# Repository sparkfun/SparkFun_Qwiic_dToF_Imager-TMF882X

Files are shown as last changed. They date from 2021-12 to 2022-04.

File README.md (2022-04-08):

SparkFun Qwiic dTof Imager TMF882X
========================================

<table class="table table-hover table-striped table-bordered">
  <tr align="center">
   <td><a href="https://www.sparkfun.com/products/19036">Qwiic dToF Imager <br />TMF8820</a></td>
   <td><a href="https://www.sparkfun.com/products/19036">Qwiic Mini dToF Imager <br />TMF8820</a></td>
   <td><a href="https://www.sparkfun.com/products/19037">Qwiic dToF Imager <br />TMF8821</a></td>
   <td><a href="https://www.sparkfun.com/products/19037">Qwiic Mini dToF Imager <br />TMF8821</a></td>
  </tr>
  <tr align="center">
   <td><i>Qwiic dToF Imager TMF8820 <br />[ <a href="https://www.sparkfun.com/products/19036">SEN-19036</a> ]</i></td>
   <td><i>Qwiic Mini dToF Imager TMF8820 <br />[ <a href="https://www.sparkfun.com/products/19218">SEN-19218</a> ]</i></td>
   <td><i>Qwiic dToF Imager TMF8821 <br />[ <a href="https://www.sparkfun.com/products/19037">SEN-19037</a> ]</i></td>
   <td><i>Qwiic Mini dToF Imager TMF8821 <br />[ <a href="https://www.sparkfun.com/products/19451">SEN-19451</a> ]</i></td>
  </tr>
</table>

<Basic description of the part.>

Repository Contents
-------------------

* **/Documentation** - Data sheets, additional product information
* **/Hardware** - Eagle design files (.brd, .sch)
* **/Production** - Production panel files (.brd)

Documentation
--------------
  
* **[Installing an Arduino Library Guide](https://learn.sparkfun.com/tutorials/installing-an-arduino-library)** - Basic information on how to install an Arduino library.
* **[Library](https://github.com/sparkfun/SparkFun_TMF882X_dToF_Arduino_Library)** - Arduino library for the Qwiic dToF TMF8820 and TMF8821.
* **[Hookup Guide](https://learn.sparkfun.com/tutorials/2289)** - Basic hookup guide for the dToF TMF8820 and TMF8821 Sensors.

Product Versions
----------------
* [SEN-19036](https://www.sparkfun.com/products/19036) - Qwiic dToF Imager TMF8820
* [SEN-19218](https://www.sparkfun.com/products/19218) - Qwiic Mini dToF Imager TMF8820
* [SEN-19037](https://www.sparkfun.com/products/19037) - Qwiic dToF Imager TMF8821
* [SEN-19451](https://www.sparkfun.com/products/19451) - Qwiic Mini dToF Imager TMF8821

Version History
---------------
* v1.0 - Initial release

License Information
-------------------

This product is _**open source**_! 

Please review the LICENSE.md file for license information. 

If you have any questions or concerns on licensing, please contact technical support on our [SparkFun forums](https://forum.sparkfun.com/viewforum.php?f=152).

Distributed as-is; no warranty is given.

- Your friends at SparkFun.

_<COLLABORATION CREDIT>_

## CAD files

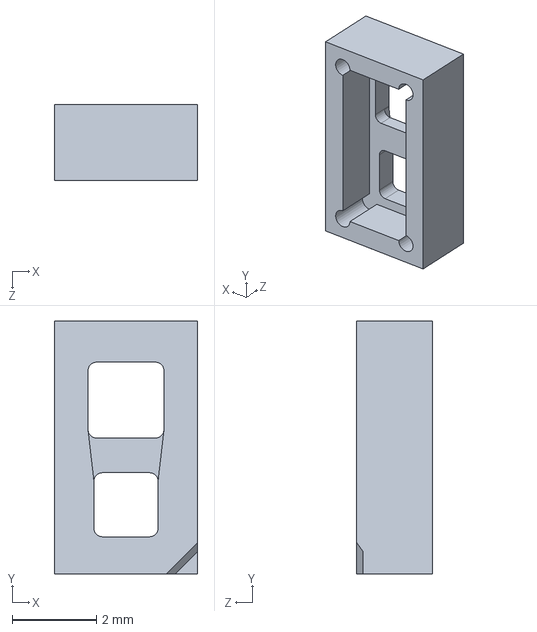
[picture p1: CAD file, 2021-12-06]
Documents/TMF882X_PD001043_1-00/RUBBERBOOT2.SLDPRT
3.40 x 6.00 x 1.80 mm

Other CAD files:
Documents/TMF882X_PD001043_1-00/RB_V2_06_02.STEP
Documents/TMF882X_PD001043_1-00/RUBBERBOOT2.SLDDRW

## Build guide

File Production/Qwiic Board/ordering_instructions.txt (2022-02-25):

panel size, 169x117mm
PCB thickness, 1.6mm
number of layers, 2
soldermask color, Red
silkscreen color, White
oz copper, 1oz
finish, HASL lead free
stencils, top
pcs per panel, 24
min trace width, 0.2032mm / 0.0080in
min drill size, 0.3048mm / 0.0120in

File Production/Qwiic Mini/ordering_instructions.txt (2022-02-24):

panel size, 169x133mm
PCB thickness, 1.6mm
number of layers, 2
soldermask color, Red
silkscreen color, White
oz copper, 1oz
finish, HASL lead free
stencils, top+bottom
pcs per panel, 54
min trace width, 0.2540mm / 0.0100in
min drill size, 0.3048mm / 0.0120in

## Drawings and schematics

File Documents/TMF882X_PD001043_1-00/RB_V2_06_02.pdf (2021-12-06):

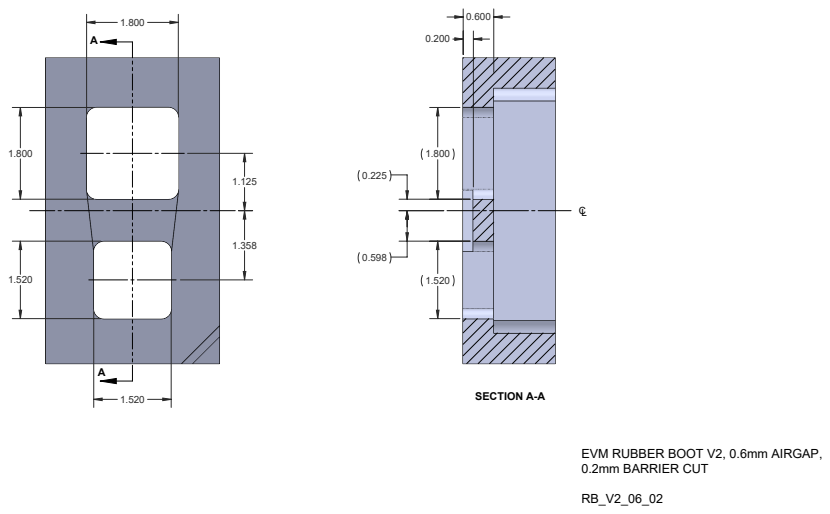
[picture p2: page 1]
SECTION A-A

EVM RUBBER BOOT V2, 0.6mm AIRGAP,
0.2mm BARRIER CUT

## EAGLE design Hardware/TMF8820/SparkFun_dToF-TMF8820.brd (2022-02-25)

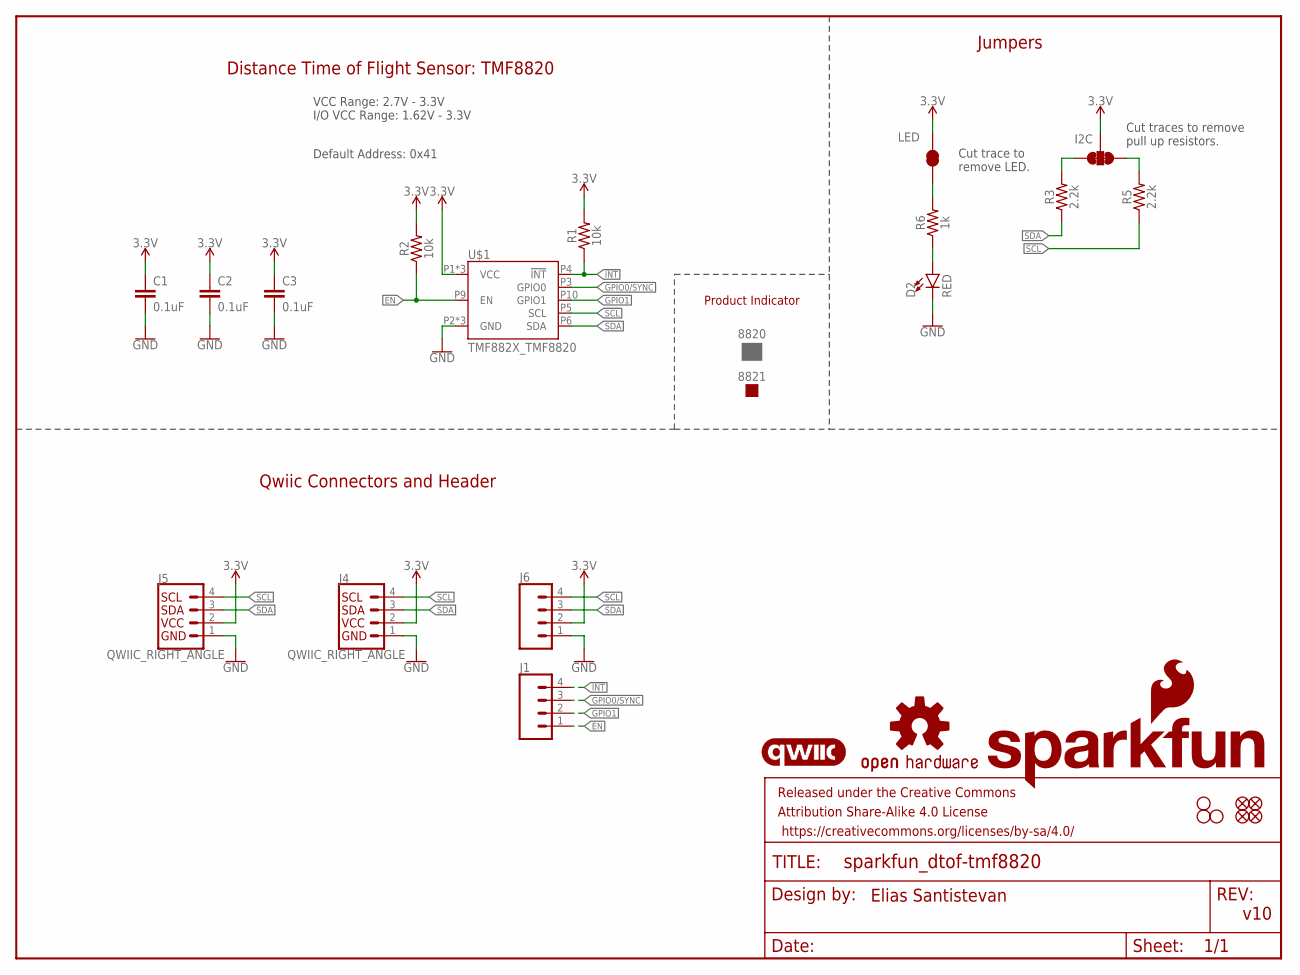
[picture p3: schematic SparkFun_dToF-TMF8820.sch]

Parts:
8820: PROD_ID_PASTE_SILK; PRODUCT_IDENT_PASTE_SILK
8821: PROD_ID_NO-PASTE_SILK; PRODUCT_IDENT_NO_SILK
C1, C2, C3: 0.1uF; 0402-TIGHT
D2: RED; LED-0603
FD5, FD6, FD7, FD8: FIDUCIALUFIDUCIAL; FIDUCIAL-MICRO
FRAME2: FRAME-LETTER; CREATIVE_COMMONS
H5, H6, H8: STAND-OFFTIGHT; STAND-OFF-TIGHT
I2C: I2C_PU; SMT-JUMPER_3_2-NC_TRACE_SILK
J1: CONN_041X04_NO_SILK_NO_POP; 1X04_NO_SILK
J4, J5: QWIIC_RIGHT_ANGLE; JST04_1MM_RA
J6: CONN_041X04_NO_SILK; 1X04_NO_SILK
LED: LED; SMT-JUMPER_2_NC_TRACE_SILK
LOGO3: SFE_LOGO_NAME_FLAME.1_INCH; SFE_LOGO_NAME_FLAME_.1
LOGO4: OSHW-LOGOS; OSHW-LOGO-S
R1, R2: 10k; 0603
R3, R5: 2.2k; 0603
R6: 1k; 0603
U$1: TMF882X_TMF8820; TMF882X
U$6: QWIIC_LOGO_5MM; QWIIC_5MM

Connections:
3.3V: C1.1, C2.1, C3.1, I2C.2, J4.2, J5.2, J6.2, LED.2, R1.2, R2.2, U$1.P1 (VCC), U$1.P7 (VCC), U$1.P12 (VCC)
!INT!: J1.4, R1.1, U$1.P4 (!INT!)
EN: J1.1, R2.1, U$1.P9 (EN)
GND: C1.2, C2.2, C3.2, D2.C, J4.1, J5.1, J6.1, U$1.P2 (GND), U$1.P8 (GND), U$1.P11 (GND)
GPIO0/SYNC: J1.3, U$1.P3 (GPIO0)
GPIO1: J1.2, U$1.P10 (GPIO1)
unnamed: D2.A, R6.1
unnamed: LED.1, R6.2
unnamed: I2C.3, R3.2
unnamed: I2C.1, R5.2
SCL: J4.4, J5.4, J6.4, R5.1, U$1.P5 (SCL)
SDA: J4.3, J5.3, J6.3, R3.1, U$1.P6 (SDA)

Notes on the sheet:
v10
Qwiic Connectors and Header
Jumpers
Cut trace to remove LED.
Cut traces to remove pull up resistors.
Elias Santistevan
Distance Time of Flight Sensor: TMF8820
VCC Range: 2.7V - 3.3V I/O VCC Range: 1.62V - 3.3V
Default Address: 0x41
Product Indicator

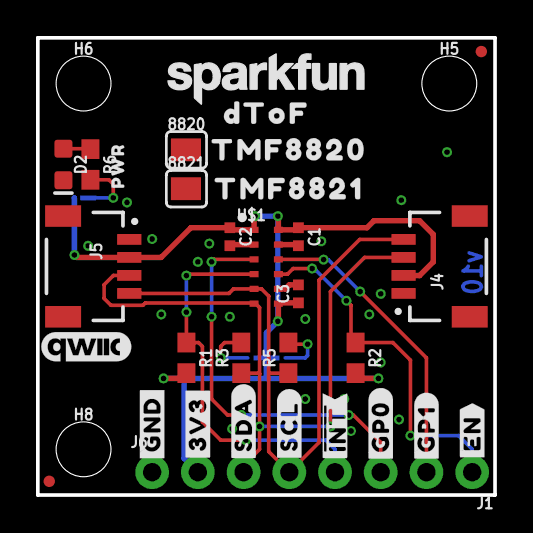
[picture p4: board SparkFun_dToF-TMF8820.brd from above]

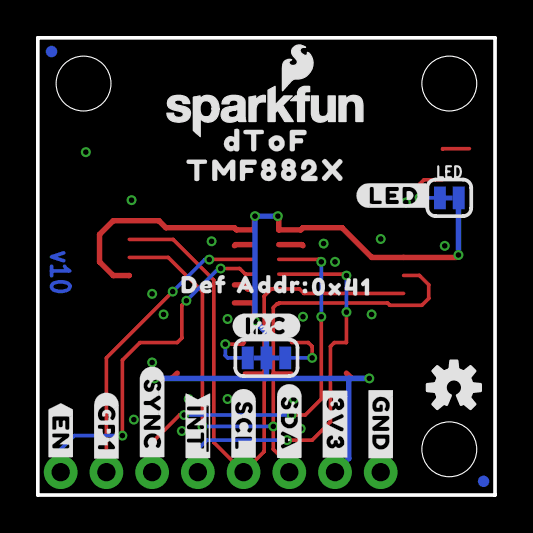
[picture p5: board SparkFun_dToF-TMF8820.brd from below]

Board: 2 copper layers, 25.4 x 25.4 mm, 57 parts (21 on the bottom side), 12 nets.

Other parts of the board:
U$2, U$16: #3V3#0
U$3, U$18: #GND#4
U$4, U$23: #SDA#6
U$5, U$21: #SCL#5
U$7, U$17: #EN#7
U$8: #GP0#19
U$9, U$19: #GP1#8
U$10: ##INT##9
U$11, U$26: DTOF882188211
U$12: TMF88209
U$13: SFE_LOGO_NAME_.1
U$14: PWR882188212
U$15: #SYNC#8
U$20: #I2C#11
U$22: #LED#10
U$24: ##INT##8
U$25: TMF882188210
U$27: TMF882X882188211
U$28: DEF11
U$29: ADDR#12
U$30: 0X4113

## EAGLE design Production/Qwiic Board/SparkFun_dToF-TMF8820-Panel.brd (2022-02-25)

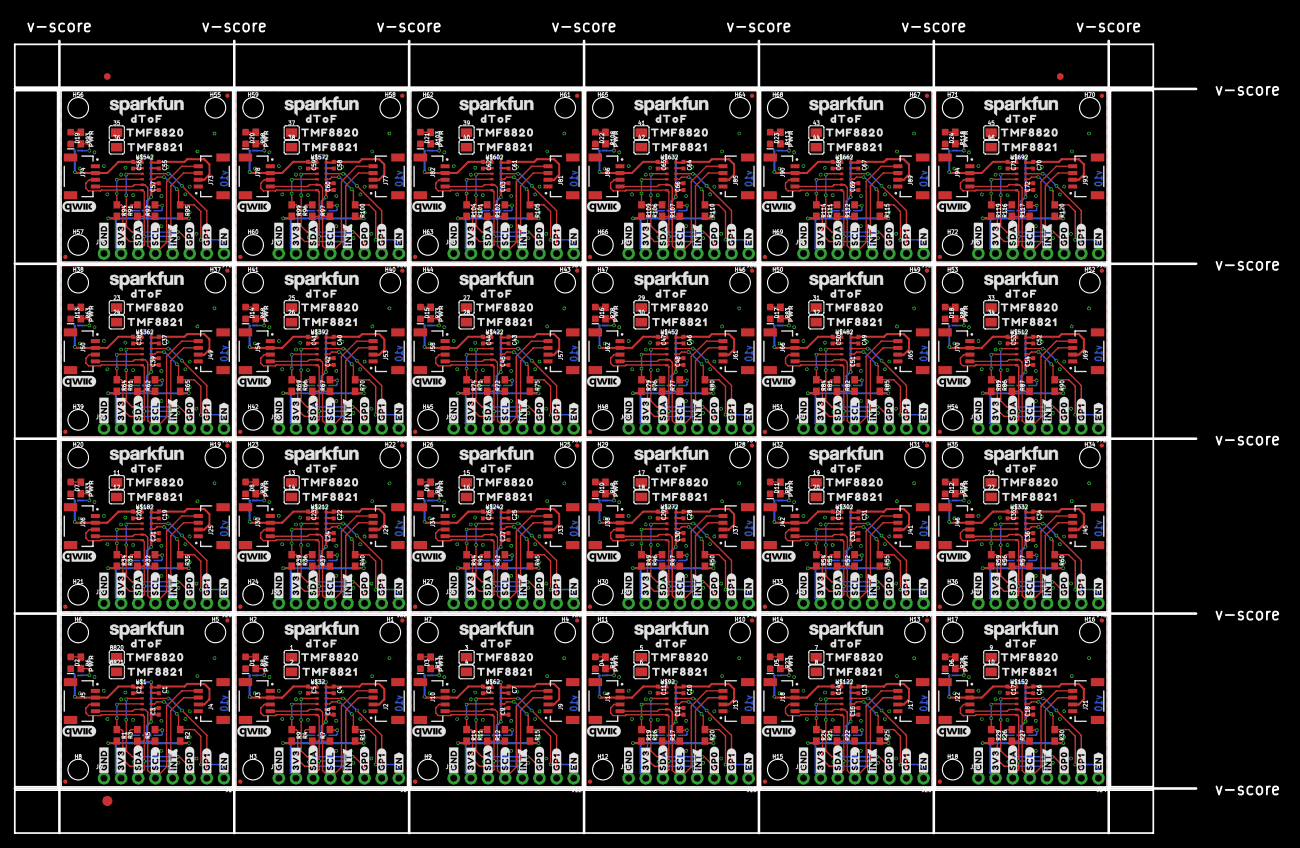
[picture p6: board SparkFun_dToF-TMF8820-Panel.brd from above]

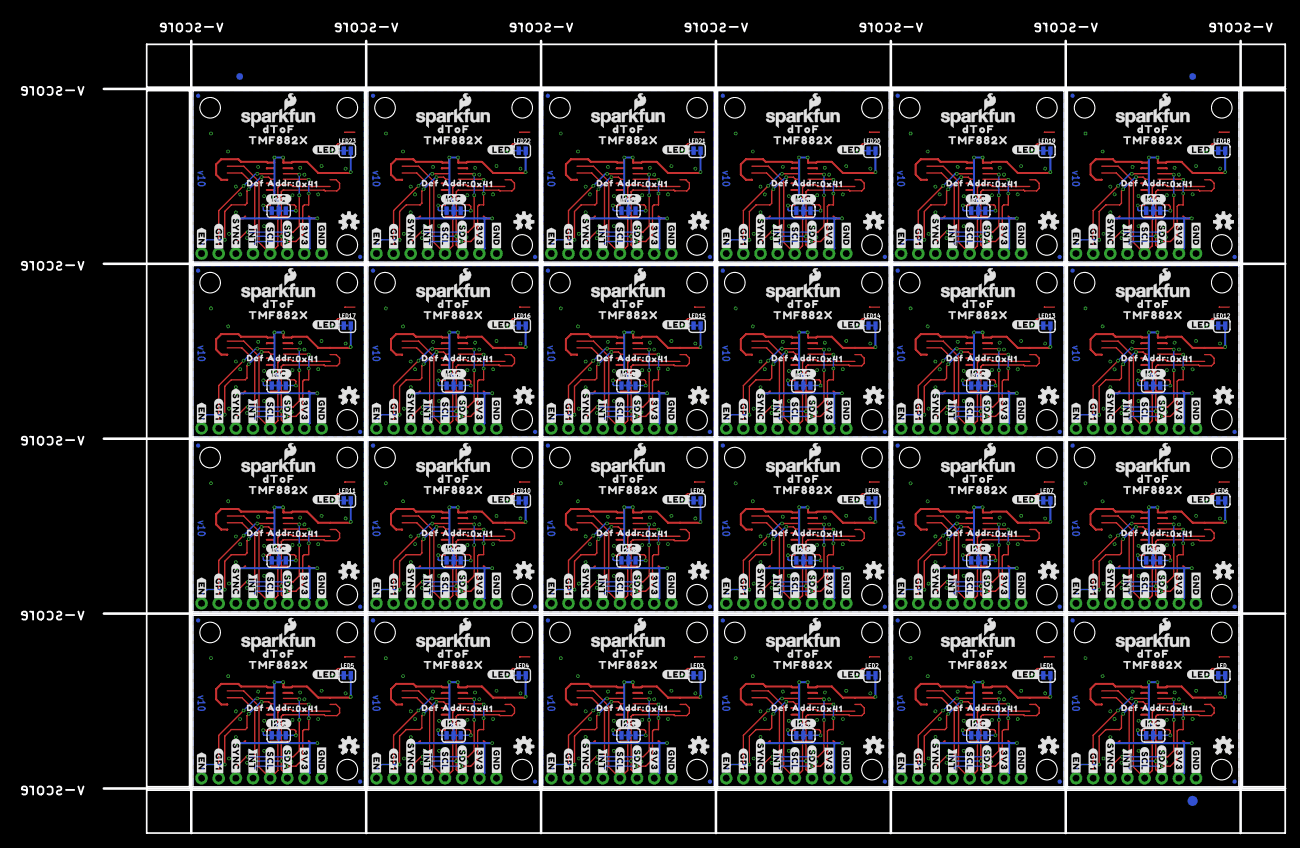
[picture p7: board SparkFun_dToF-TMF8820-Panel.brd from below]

Board: 2 copper layers, 175.0 x 117.3 mm, 1350 parts (507 on the bottom side), 288 nets.

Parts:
1, 3, 5, 7, 9, 11, 13, 15, 17, 19, 21, 23, 25, 27, 29, 31, 33, 35, 37, 39, 41, 43, 45, 8820: PROD_ID_PASTE_SILK; PRODUCT_IDENT_PASTE_SILK
2, 4, 6, 8, 10, 12, 14, 16, 18, 20, 22, 24, 26, 28, 30, 32, 34, 36, 38, 40, 42, 44, 46, 8821: PROD_ID_NO-PASTE_SILK; PRODUCT_IDENT_NO_SILK
C1, C2, C3, C4, C5, C6, C7, C8, C9, C10, C11, C12, C13, C14, C15, C16, C17, C18, C19, C20, C21, C22, C23, C24, C25, C26, C27, C28, C29, C30, C31, C32, C33, C34, C35, C36, C37, C38, C39, C40, C41, C42, C43, C44, C45, C46, C47, C48, C49, C50, C51, C52, C53, C54, C55, C56, C57, C58, C59, C60, C61, C62, C63, C64, C65, C66, C67, C68, C69, C70, C71, C72: 0.1uF; 0402-TIGHT
D1, D2, D3, D4, D5, D6, D7, D8, D9, D10, D11, D12, D13, D14, D15, D16, D17, D18, D19, D20, D21, D22, D23, D24: RED; LED-0603
E$1, E$2, E$3, E$4: FIDUCIAL-1X2
E$5, E$6: FIDUCIAL-1.5X3
FD1, FD2, FD3, FD4, FD5, FD6, FD7, FD8, FD9, FD10, FD11, FD12, FD13, FD14, FD15, FD16, FD17, FD18, FD19, FD20, FD21, FD22, FD23, FD24, FD25, FD26, FD27, FD28, FD29, FD30, FD31, FD32, FD33, FD34, FD35, FD36, FD37, FD38, FD39, FD40, FD41, FD42, FD43, FD44, FD45, FD46, FD47, FD48, FD49, FD50, FD51, FD52, FD53, FD54, FD55, FD56, FD57, FD58, FD59, FD60, FD61, FD62, FD63, FD64, FD65, FD66, FD67, FD68, FD69, FD70, FD71, FD72, FD73, FD74, FD75, FD76, FD77, FD78, FD79, FD80, FD81, FD82, FD83, FD84, FD85, FD86, FD87, FD88, FD89, FD90, FD91, FD92, FD93, FD94, FD95, FD96: FIDUCIALUFIDUCIAL; FIDUCIAL-MICRO
H1, H2, H3, H4, H5, H6, H7, H8, H9, H10, H11, H12, H13, H14, H15, H16, H17, H18, H19, H20, H21, H22, H23, H24, H25, H26, H27, H28, H29, H30, H31, H32, H33, H34, H35, H36, H37, H38, H39, H40, H41, H42, H43, H44, H45, H46, H47, H48, H49, H50, H51, H52, H53, H54, H55, H56, H57, H58, H59, H60, H61, H62, H63, H64, H65, H66, H67, H68, H69, H70, H71, H72: STAND-OFFTIGHT; STAND-OFF-TIGHT
I2C, I2C1, I2C2, I2C3, I2C4, I2C5, I2C6, I2C7, I2C8, I2C9, I2C10, I2C11, I2C12, I2C13, I2C14, I2C15, I2C16, I2C17, I2C18, I2C19, I2C20, I2C21, I2C22, I2C23: I2C_PU; SMT-JUMPER_3_2-NC_TRACE_SILK
J1, J6, J7, J8, J11, J12, J15, J16, J19, J20, J23, J24, J27, J28, J31, J32, J35, J36, J39, J40, J43, J44, J47, J48, J51, J52, J55, J56, J59, J60, J63, J64, J67, J68, J71, J72, J75, J76, J79, J80, J83, J84, J87, J88, J91, J92, J95, J96: 1X04_NO_SILK
J2, J3, J4, J5, J9, J10, J13, J14, J17, J18, J21, J22, J25, J26, J29, J30, J33, J34, J37, J38, J41, J42, J45, J46, J49, J50, J53, J54, J57, J58, J61, J62, J65, J66, J69, J70, J73, J74, J77, J78, J81, J82, J85, J86, J89, J90, J93, J94: QWIIC_RIGHT_ANGLE; JST04_1MM_RA
LED, LED1, LED2, LED3, LED4, LED5, LED6, LED7, LED8, LED9, LED10, LED11, LED12, LED13, LED14, LED15, LED16, LED17, LED18, LED19, LED20, LED21, LED22, LED23: LED; SMT-JUMPER_2_NC_TRACE_SILK
LOGO1, LOGO3, LOGO5, LOGO7, LOGO9, LOGO11, LOGO13, LOGO15, LOGO17, LOGO19, LOGO21, LOGO23, LOGO25, LOGO27, LOGO29, LOGO31, LOGO33, LOGO35, LOGO37, LOGO39, LOGO41, LOGO43, LOGO45, LOGO47: SFE_LOGO_NAME_FLAME.1_INCH; SFE_LOGO_NAME_FLAME_.1
LOGO2, LOGO4, LOGO6, LOGO8, LOGO10, LOGO12, LOGO14, LOGO16, LOGO18, LOGO20, LOGO22, LOGO24, LOGO26, LOGO28, LOGO30, LOGO32, LOGO34, LOGO36, LOGO38, LOGO40, LOGO42, LOGO44, LOGO46, LOGO48: OSHW-LOGOS; OSHW-LOGO-S
R1, R2, R9, R10, R14, R15, R19, R20, R24, R25, R29, R30, R34, R35, R39, R40, R44, R45, R49, R50, R54, R55, R59, R60, R64, R65, R69, R70, R74, R75, R79, R80, R84, R85, R89, R90, R94, R95, R99, R100, R104, R105, R109, R110, R114, R115, R119, R120: 10k; 0603
R3, R4, R5, R7, R11, R12, R16, R17, R21, R22, R26, R27, R31, R32, R36, R37, R41, R42, R46, R47, R51, R52, R56, R57, R61, R62, R66, R67, R71, R72, R76, R77, R81, R82, R86, R87, R91, R92, R96, R97, R101, R102, R106, R107, R111, R112, R116, R117: 2.2k; 0603
R6, R8, R13, R18, R23, R28, R33, R38, R43, R48, R53, R58, R63, R68, R73, R78, R83, R88, R93, R98, R103, R108, R113, R118: 1k; 0603
U$1, U$32, U$62, U$92, U$122, U$152, U$182, U$212, U$242, U$272, U$302, U$332, U$362, U$392, U$422, U$452, U$482, U$512, U$542, U$572, U$602, U$632, U$662, U$692: TMF882X_TMF8820; TMF882X
U$2, U$16, U$33, U$39, U$63, U$69, U$93, U$99, U$123, U$129, U$153, U$159, U$183, U$189, U$213, U$219, U$243, U$249, U$273, U$279, U$303, U$309, U$333, U$339, U$363, U$369, U$393, U$399, U$423, U$429, U$453, U$459, U$483, U$489, U$513, U$519, U$543, U$549, U$573, U$579, U$603, U$609, U$633, U$639, U$663, U$669, U$693, U$699: #3V3#0
U$3, U$18, U$34, U$41, U$64, U$71, U$94, U$101, U$124, U$131, U$154, U$161, U$184, U$191, U$214, U$221, U$244, U$251, U$274, U$281, U$304, U$311, U$334, U$341, U$364, U$371, U$394, U$401, U$424, U$431, U$454, U$461, U$484, U$491, U$514, U$521, U$544, U$551, U$574, U$581, U$604, U$611, U$634, U$641, U$664, U$671, U$694, U$701: #GND#4
U$4, U$23, U$35, U$45, U$65, U$75, U$95, U$105, U$125, U$135, U$155, U$165, U$185, U$195, U$215, U$225, U$245, U$255, U$275, U$285, U$305, U$315, U$335, U$345, U$365, U$375, U$395, U$405, U$425, U$435, U$455, U$465, U$485, U$495, U$515, U$525, U$545, U$555, U$575, U$585, U$605, U$615, U$635, U$645, U$665, U$675, U$695, U$705: #SDA#6
U$5, U$21, U$36, U$44, U$66, U$74, U$96, U$104, U$126, U$134, U$156, U$164, U$186, U$194, U$216, U$224, U$246, U$254, U$276, U$284, U$306, U$314, U$336, U$344, U$366, U$374, U$396, U$404, U$426, U$434, U$456, U$464, U$486, U$494, U$516, U$524, U$546, U$554, U$576, U$584, U$606, U$614, U$636, U$644, U$666, U$674, U$696, U$704: #SCL#5
U$6, U$31, U$61, U$91, U$121, U$151, U$181, U$211, U$241, U$271, U$301, U$331, U$361, U$391, U$421, U$451, U$481, U$511, U$541, U$571, U$601, U$631, U$661, U$691: QWIIC_LOGO_5MM; QWIIC_5MM
U$7, U$17, U$37, U$40, U$67, U$70, U$97, U$100, U$127, U$130, U$157, U$160, U$187, U$190, U$217, U$220, U$247, U$250, U$277, U$280, U$307, U$310, U$337, U$340, U$367, U$370, U$397, U$400, U$427, U$430, U$457, U$460, U$487, U$490, U$517, U$520, U$547, U$550, U$577, U$580, U$607, U$610, U$637, U$640, U$667, U$670, U$697, U$700: #EN#7
U$8, U$58, U$88, U$118, U$148, U$178, U$208, U$238, U$268, U$298, U$328, U$358, U$388, U$418, U$448, U$478, U$508, U$538, U$568, U$598, U$628, U$658, U$688, U$718: #GP0#19
U$9, U$19, U$59, U$60, U$89, U$90, U$119, U$120, U$149, U$150, U$179, U$180, U$209, U$210, U$239, U$240, U$269, U$270, U$299, U$300, U$329, U$330, U$359, U$360, U$389, U$390, U$419, U$420, U$449, U$450, U$479, U$480, U$509, U$510, U$539, U$540, U$569, U$570, U$599, U$600, U$629, U$630, U$659, U$660, U$689, U$690, U$719, U$720: #GP1#8
U$10, U$49, U$79, U$109, U$139, U$169, U$199, U$229, U$259, U$289, U$319, U$349, U$379, U$409, U$439, U$469, U$499, U$529, U$559, U$589, U$619, U$649, U$679, U$709: ##INT##9
U$11, U$26, U$50, U$54, U$80, U$84, U$110, U$114, U$140, U$144, U$170, U$174, U$200, U$204, U$230, U$234, U$260, U$264, U$290, U$294, U$320, U$324, U$350, U$354, U$380, U$384, U$410, U$414, U$440, U$444, U$470, U$474, U$500, U$504, U$530, U$534, U$560, U$564, U$590, U$594, U$620, U$624, U$650, U$654, U$680, U$684, U$710, U$714: DTOF882188211
U$12, U$51, U$81, U$111, U$141, U$171, U$201, U$231, U$261, U$291, U$321, U$351, U$381, U$411, U$441, U$471, U$501, U$531, U$561, U$591, U$621, U$651, U$681, U$711: TMF88209
U$13, U$55, U$85, U$115, U$145, U$175, U$205, U$235, U$265, U$295, U$325, U$355, U$385, U$415, U$445, U$475, U$505, U$535, U$565, U$595, U$625, U$655, U$685, U$715: SFE_LOGO_NAME_.1
U$14, U$38, U$68, U$98, U$128, U$158, U$188, U$218, U$248, U$278, U$308, U$338, U$368, U$398, U$428, U$458, U$488, U$518, U$548, U$578, U$608, U$638, U$668, U$698: PWR882188212
U$15, U$52, U$82, U$112, U$142, U$172, U$202, U$232, U$262, U$292, U$322, U$352, U$382, U$412, U$442, U$472, U$502, U$532, U$562, U$592, U$622, U$652, U$682, U$712: #SYNC#8
U$20, U$42, U$72, U$102, U$132, U$162, U$192, U$222, U$252, U$282, U$312, U$342, U$372, U$402, U$432, U$462, U$492, U$522, U$552, U$582, U$612, U$642, U$672, U$702: #I2C#11
U$22, U$43, U$73, U$103, U$133, U$163, U$193, U$223, U$253, U$283, U$313, U$343, U$373, U$403, U$433, U$463, U$493, U$523, U$553, U$583, U$613, U$643, U$673, U$703: #LED#10
U$24, U$53, U$83, U$113, U$143, U$173, U$203, U$233, U$263, U$293, U$323, U$353, U$383, U$413, U$443, U$473, U$503, U$533, U$563, U$593, U$623, U$653, U$683, U$713: ##INT##8
U$25, U$56, U$86, U$116, U$146, U$176, U$206, U$236, U$266, U$296, U$326, U$356, U$386, U$416, U$446, U$476, U$506, U$536, U$566, U$596, U$626, U$656, U$686, U$716: TMF882188210
U$27, U$57, U$87, U$117, U$147, U$177, U$207, U$237, U$267, U$297, U$327, U$357, U$387, U$417, U$447, U$477, U$507, U$537, U$567, U$597, U$627, U$657, U$687, U$717: TMF882X882188211
U$28, U$46, U$76, U$106, U$136, U$166, U$196, U$226, U$256, U$286, U$316, U$346, U$376, U$406, U$436, U$466, U$496, U$526, U$556, U$586, U$616, U$646, U$676, U$706: DEF11
U$29, U$47, U$77, U$107, U$137, U$167, U$197, U$227, U$257, U$287, U$317, U$347, U$377, U$407, U$437, U$467, U$497, U$527, U$557, U$587, U$617, U$647, U$677, U$707: ADDR#12
U$30, U$48, U$78, U$108, U$138, U$168, U$198, U$228, U$258, U$288, U$318, U$348, U$378, U$408, U$438, U$468, U$498, U$528, U$558, U$588, U$618, U$648, U$678, U$708: 0X4113

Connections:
3.3V: C1.1, C2.1, C3.1, I2C.2, J4.2, J5.2, J6.2, LED.2, R1.2, R2.2, U$1.P1, U$1.P7, U$1.P12
3.3V1: C4.1, C5.1, C6.1, I2C1.2, J2.2, J3.2, J7.2, LED1.2, R9.2, R10.2, U$32.P1, U$32.P7, U$32.P12
3.3V2: C7.1, C8.1, C9.1, I2C2.2, J9.2, J10.2, J11.2, LED2.2, R14.2, R15.2, U$62.P1, U$62.P7, U$62.P12
3.3V3: C10.1, C11.1, C12.1, I2C3.2, J13.2, J14.2, J15.2, LED3.2, R19.2, R20.2, U$92.P1, U$92.P7, U$92.P12
3.3V4: C13.1, C14.1, C15.1, I2C4.2, J17.2, J18.2, J19.2, LED4.2, R24.2, R25.2, U$122.P1, U$122.P7, U$122.P12
3.3V5: C16.1, C17.1, C18.1, I2C5.2, J21.2, J22.2, J23.2, LED5.2, R29.2, R30.2, U$152.P1, U$152.P7, U$152.P12
3.3V6: C19.1, C20.1, C21.1, I2C6.2, J25.2, J26.2, J27.2, LED6.2, R34.2, R35.2, U$182.P1, U$182.P7, U$182.P12
3.3V7: C22.1, C23.1, C24.1, I2C7.2, J29.2, J30.2, J31.2, LED7.2, R39.2, R40.2, U$212.P1, U$212.P7, U$212.P12
3.3V8: C25.1, C26.1, C27.1, I2C8.2, J33.2, J34.2, J35.2, LED8.2, R44.2, R45.2, U$242.P1, U$242.P7, U$242.P12
3.3V9: C28.1, C29.1, C30.1, I2C9.2, J37.2, J38.2, J39.2, LED9.2, R49.2, R50.2, U$272.P1, U$272.P7, U$272.P12
3.3V10: C31.1, C32.1, C33.1, I2C10.2, J41.2, J42.2, J43.2, LED10.2, R54.2, R55.2, U$302.P1, U$302.P7, U$302.P12
3.3V11: C34.1, C35.1, C36.1, I2C11.2, J45.2, J46.2, J47.2, LED11.2, R59.2, R60.2, U$332.P1, U$332.P7, U$332.P12
3.3V12: C37.1, C38.1, C39.1, I2C12.2, J49.2, J50.2, J51.2, LED12.2, R64.2, R65.2, U$362.P1, U$362.P7, U$362.P12
3.3V13: C40.1, C41.1, C42.1, I2C13.2, J53.2, J54.2, J55.2, LED13.2, R69.2, R70.2, U$392.P1, U$392.P7, U$392.P12
3.3V14: C43.1, C44.1, C45.1, I2C14.2, J57.2, J58.2, J59.2, LED14.2, R74.2, R75.2, U$422.P1, U$422.P7, U$422.P12
3.3V15: C46.1, C47.1, C48.1, I2C15.2, J61.2, J62.2, J63.2, LED15.2, R79.2, R80.2, U$452.P1, U$452.P7, U$452.P12
3.3V16: C49.1, C50.1, C51.1, I2C16.2, J65.2, J66.2, J67.2, LED16.2, R84.2, R85.2, U$482.P1, U$482.P7, U$482.P12
3.3V17: C52.1, C53.1, C54.1, I2C17.2, J69.2, J70.2, J71.2, LED17.2, R89.2, R90.2, U$512.P1, U$512.P7, U$512.P12
3.3V18: C55.1, C56.1, C57.1, I2C18.2, J73.2, J74.2, J75.2, LED18.2, R94.2, R95.2, U$542.P1, U$542.P7, U$542.P12
3.3V19: C58.1, C59.1, C60.1, I2C19.2, J77.2, J78.2, J79.2, LED19.2, R99.2, R100.2, U$572.P1, U$572.P7, U$572.P12
3.3V20: C61.1, C62.1, C63.1, I2C20.2, J81.2, J82.2, J83.2, LED20.2, R104.2, R105.2, U$602.P1, U$602.P7, U$602.P12
3.3V21: C64.1, C65.1, C66.1, I2C21.2, J85.2, J86.2, J87.2, LED21.2, R109.2, R110.2, U$632.P1, U$632.P7, U$632.P12
3.3V22: C67.1, C68.1, C69.1, I2C22.2, J89.2, J90.2, J91.2, LED22.2, R114.2, R115.2, U$662.P1, U$662.P7, U$662.P12
3.3V23: C70.1, C71.1, C72.1, I2C23.2, J93.2, J94.2, J95.2, LED23.2, R119.2, R120.2, U$692.P1, U$692.P7, U$692.P12
!INT!: J1.4, R1.1, U$1.P4
!INT!1: J8.4, R9.1, U$32.P4
!INT!2: J12.4, R14.1, U$62.P4
!INT!3: J16.4, R19.1, U$92.P4
!INT!4: J20.4, R24.1, U$122.P4
!INT!5: J24.4, R29.1, U$152.P4
!INT!6: J28.4, R34.1, U$182.P4
!INT!7: J32.4, R39.1, U$212.P4
!INT!8: J36.4, R44.1, U$242.P4
!INT!9: J40.4, R49.1, U$272.P4
!INT!10: J44.4, R54.1, U$302.P4
!INT!11: J48.4, R59.1, U$332.P4
!INT!12: J52.4, R64.1, U$362.P4
!INT!13: J56.4, R69.1, U$392.P4
!INT!14: J60.4, R74.1, U$422.P4
!INT!15: J64.4, R79.1, U$452.P4
!INT!16: J68.4, R84.1, U$482.P4
!INT!17: J72.4, R89.1, U$512.P4
!INT!18: J76.4, R94.1, U$542.P4
!INT!19: J80.4, R99.1, U$572.P4
!INT!20: J84.4, R104.1, U$602.P4
!INT!21: J88.4, R109.1, U$632.P4
!INT!22: J92.4, R114.1, U$662.P4
!INT!23: J96.4, R119.1, U$692.P4
EN: J1.1, R2.1, U$1.P9
EN1: J8.1, R10.1, U$32.P9
EN2: J12.1, R15.1, U$62.P9
EN3: J16.1, R20.1, U$92.P9
EN4: J20.1, R25.1, U$122.P9
EN5: J24.1, R30.1, U$152.P9
EN6: J28.1, R35.1, U$182.P9
EN7: J32.1, R40.1, U$212.P9
EN8: J36.1, R45.1, U$242.P9
EN9: J40.1, R50.1, U$272.P9
EN10: J44.1, R55.1, U$302.P9
EN11: J48.1, R60.1, U$332.P9
EN12: J52.1, R65.1, U$362.P9
EN13: J56.1, R70.1, U$392.P9
EN14: J60.1, R75.1, U$422.P9
EN15: J64.1, R80.1, U$452.P9
EN16: J68.1, R85.1, U$482.P9
EN17: J72.1, R90.1, U$512.P9
EN18: J76.1, R95.1, U$542.P9
EN19: J80.1, R100.1, U$572.P9
EN20: J84.1, R105.1, U$602.P9
EN21: J88.1, R110.1, U$632.P9
EN22: J92.1, R115.1, U$662.P9
EN23: J96.1, R120.1, U$692.P9
GND: C1.2, C2.2, C3.2, D2.C, J4.1, J5.1, J6.1, U$1.P2, U$1.P8, U$1.P11
GND1: C4.2, C5.2, C6.2, D1.C, J2.1, J3.1, J7.1, U$32.P2, U$32.P8, U$32.P11
GND2: C7.2, C8.2, C9.2, D3.C, J9.1, J10.1, J11.1, U$62.P2, U$62.P8, U$62.P11
GND3: C10.2, C11.2, C12.2, D4.C, J13.1, J14.1, J15.1, U$92.P2, U$92.P8, U$92.P11
GND4: C13.2, C14.2, C15.2, D5.C, J17.1, J18.1, J19.1, U$122.P2, U$122.P8, U$122.P11
GND5: C16.2, C17.2, C18.2, D6.C, J21.1, J22.1, J23.1, U$152.P2, U$152.P8, U$152.P11
GND6: C19.2, C20.2, C21.2, D7.C, J25.1, J26.1, J27.1, U$182.P2, U$182.P8, U$182.P11
GND7: C22.2, C23.2, C24.2, D8.C, J29.1, J30.1, J31.1, U$212.P2, U$212.P8, U$212.P11
GND8: C25.2, C26.2, C27.2, D9.C, J33.1, J34.1, J35.1, U$242.P2, U$242.P8, U$242.P11
GND9: C28.2, C29.2, C30.2, D10.C, J37.1, J38.1, J39.1, U$272.P2, U$272.P8, U$272.P11
GND10: C31.2, C32.2, C33.2, D11.C, J41.1, J42.1, J43.1, U$302.P2, U$302.P8, U$302.P11
GND11: C34.2, C35.2, C36.2, D12.C, J45.1, J46.1, J47.1, U$332.P2, U$332.P8, U$332.P11
GND12: C37.2, C38.2, C39.2, D13.C, J49.1, J50.1, J51.1, U$362.P2, U$362.P8, U$362.P11
GND13: C40.2, C41.2, C42.2, D14.C, J53.1, J54.1, J55.1, U$392.P2, U$392.P8, U$392.P11
GND14: C43.2, C44.2, C45.2, D15.C, J57.1, J58.1, J59.1, U$422.P2, U$422.P8, U$422.P11
GND15: C46.2, C47.2, C48.2, D16.C, J61.1, J62.1, J63.1, U$452.P2, U$452.P8, U$452.P11
GND16: C49.2, C50.2, C51.2, D17.C, J65.1, J66.1, J67.1, U$482.P2, U$482.P8, U$482.P11
GND17: C52.2, C53.2, C54.2, D18.C, J69.1, J70.1, J71.1, U$512.P2, U$512.P8, U$512.P11
GND18: C55.2, C56.2, C57.2, D19.C, J73.1, J74.1, J75.1, U$542.P2, U$542.P8, U$542.P11
GND19: C58.2, C59.2, C60.2, D20.C, J77.1, J78.1, J79.1, U$572.P2, U$572.P8, U$572.P11
GND20: C61.2, C62.2, C63.2, D21.C, J81.1, J82.1, J83.1, U$602.P2, U$602.P8, U$602.P11
GND21: C64.2, C65.2, C66.2, D22.C, J85.1, J86.1, J87.1, U$632.P2, U$632.P8, U$632.P11
GND22: C67.2, C68.2, C69.2, D23.C, J89.1, J90.1, J91.1, U$662.P2, U$662.P8, U$662.P11
GND23: C70.2, C71.2, C72.2, D24.C, J93.1, J94.1, J95.1, U$692.P2, U$692.P8, U$692.P11
GPIO0/SYNC: J1.3, U$1.P3
GPIO0/SYNC1: J8.3, U$32.P3
GPIO0/SYNC2: J12.3, U$62.P3
GPIO0/SYNC3: J16.3, U$92.P3
GPIO0/SYNC4: J20.3, U$122.P3
GPIO0/SYNC5: J24.3, U$152.P3
GPIO0/SYNC6: J28.3, U$182.P3
GPIO0/SYNC7: J32.3, U$212.P3
GPIO0/SYNC8: J36.3, U$242.P3
GPIO0/SYNC9: J40.3, U$272.P3
GPIO0/SYNC10: J44.3, U$302.P3
GPIO0/SYNC11: J48.3, U$332.P3
GPIO0/SYNC12: J52.3, U$362.P3
GPIO0/SYNC13: J56.3, U$392.P3
GPIO0/SYNC14: J60.3, U$422.P3
GPIO0/SYNC15: J64.3, U$452.P3
GPIO0/SYNC16: J68.3, U$482.P3
GPIO0/SYNC17: J72.3, U$512.P3
GPIO0/SYNC18: J76.3, U$542.P3
GPIO0/SYNC19: J80.3, U$572.P3
GPIO0/SYNC20: J84.3, U$602.P3
GPIO0/SYNC21: J88.3, U$632.P3
GPIO0/SYNC22: J92.3, U$662.P3
GPIO0/SYNC23: J96.3, U$692.P3
GPIO1: J1.2, U$1.P10
GPIO2: J8.2, U$32.P10
GPIO3: J12.2, U$62.P10
GPIO4: J16.2, U$92.P10
GPIO5: J20.2, U$122.P10
GPIO6: J24.2, U$152.P10
GPIO7: J28.2, U$182.P10
GPIO8: J32.2, U$212.P10
GPIO9: J36.2, U$242.P10
GPIO10: J40.2, U$272.P10
GPIO11: J44.2, U$302.P10
GPIO12: J48.2, U$332.P10
GPIO13: J52.2, U$362.P10
GPIO14: J56.2, U$392.P10
GPIO15: J60.2, U$422.P10
GPIO16: J64.2, U$452.P10
GPIO17: J68.2, U$482.P10
GPIO18: J72.2, U$512.P10
GPIO19: J76.2, U$542.P10
GPIO20: J80.2, U$572.P10
GPIO21: J84.2, U$602.P10
GPIO22: J88.2, U$632.P10
GPIO23: J92.2, U$662.P10
GPIO24: J96.2, U$692.P10
unnamed: D1.A, R8.1
unnamed: LED1.1, R8.2
unnamed: I2C1.3, R4.2
unnamed: I2C1.1, R7.2
unnamed: D2.A, R6.1
unnamed: LED.1, R6.2
unnamed: I2C.3, R3.2
unnamed: I2C.1, R5.2
unnamed: D3.A, R13.1
unnamed: LED2.1, R13.2
unnamed: I2C2.3, R11.2
unnamed: I2C2.1, R12.2
unnamed: D4.A, R18.1
unnamed: LED3.1, R18.2
unnamed: I2C3.3, R16.2
unnamed: I2C3.1, R17.2
unnamed: D5.A, R23.1
unnamed: LED4.1, R23.2
unnamed: I2C4.3, R21.2
unnamed: I2C4.1, R22.2
unnamed: D6.A, R28.1
unnamed: LED5.1, R28.2
unnamed: I2C5.3, R26.2
unnamed: I2C5.1, R27.2
unnamed: D7.A, R33.1
unnamed: LED6.1, R33.2
unnamed: I2C6.3, R31.2
unnamed: I2C6.1, R32.2
unnamed: D8.A, R38.1
unnamed: LED7.1, R38.2
unnamed: I2C7.3, R36.2
unnamed: I2C7.1, R37.2
unnamed: D9.A, R43.1
unnamed: LED8.1, R43.2
unnamed: I2C8.3, R41.2
unnamed: I2C8.1, R42.2
unnamed: D10.A, R48.1
unnamed: LED9.1, R48.2
unnamed: I2C9.3, R46.2
unnamed: I2C9.1, R47.2
unnamed: D11.A, R53.1
unnamed: LED10.1, R53.2
unnamed: I2C10.3, R51.2
unnamed: I2C10.1, R52.2
unnamed: D12.A, R58.1
unnamed: LED11.1, R58.2
unnamed: I2C11.3, R56.2
unnamed: I2C11.1, R57.2
unnamed: D13.A, R63.1
unnamed: LED12.1, R63.2
unnamed: I2C12.3, R61.2
unnamed: I2C12.1, R62.2
unnamed: D14.A, R68.1
unnamed: LED13.1, R68.2
unnamed: I2C13.3, R66.2
unnamed: I2C13.1, R67.2
unnamed: D15.A, R73.1
unnamed: LED14.1, R73.2
unnamed: I2C14.3, R71.2
unnamed: I2C14.1, R72.2
unnamed: D16.A, R78.1
unnamed: LED15.1, R78.2
unnamed: I2C15.3, R76.2
unnamed: I2C15.1, R77.2
unnamed: D17.A, R83.1
unnamed: LED16.1, R83.2
unnamed: I2C16.3, R81.2
unnamed: I2C16.1, R82.2
unnamed: D18.A, R88.1
unnamed: LED17.1, R88.2
unnamed: I2C17.3, R86.2
unnamed: I2C17.1, R87.2
unnamed: D19.A, R93.1
unnamed: LED18.1, R93.2
unnamed: I2C18.3, R91.2
unnamed: I2C18.1, R92.2
unnamed: D20.A, R98.1
unnamed: LED19.1, R98.2
unnamed: I2C19.3, R96.2
unnamed: I2C19.1, R97.2
unnamed: D21.A, R103.1
unnamed: LED20.1, R103.2
unnamed: I2C20.3, R101.2
unnamed: I2C20.1, R102.2
unnamed: D22.A, R108.1
unnamed: LED21.1, R108.2
unnamed: I2C21.3, R106.2
unnamed: I2C21.1, R107.2
unnamed: D23.A, R113.1
unnamed: LED22.1, R113.2
unnamed: I2C22.3, R111.2
unnamed: I2C22.1, R112.2
unnamed: D24.A, R118.1
unnamed: LED23.1, R118.2
unnamed: I2C23.3, R116.2
unnamed: I2C23.1, R117.2
SCL: J4.4, J5.4, J6.4, R5.1, U$1.P5
SCL1: J2.4, J3.4, J7.4, R7.1, U$32.P5
SCL2: J9.4, J10.4, J11.4, R12.1, U$62.P5
SCL3: J13.4, J14.4, J15.4, R17.1, U$92.P5
SCL4: J17.4, J18.4, J19.4, R22.1, U$122.P5
SCL5: J21.4, J22.4, J23.4, R27.1, U$152.P5
SCL6: J25.4, J26.4, J27.4, R32.1, U$182.P5
SCL7: J29.4, J30.4, J31.4, R37.1, U$212.P5
SCL8: J33.4, J34.4, J35.4, R42.1, U$242.P5
SCL9: J37.4, J38.4, J39.4, R47.1, U$272.P5
SCL10: J41.4, J42.4, J43.4, R52.1, U$302.P5
SCL11: J45.4, J46.4, J47.4, R57.1, U$332.P5
SCL12: J49.4, J50.4, J51.4, R62.1, U$362.P5
SCL13: J53.4, J54.4, J55.4, R67.1, U$392.P5
SCL14: J57.4, J58.4, J59.4, R72.1, U$422.P5
SCL15: J61.4, J62.4, J63.4, R77.1, U$452.P5
SCL16: J65.4, J66.4, J67.4, R82.1, U$482.P5
SCL17: J69.4, J70.4, J71.4, R87.1, U$512.P5
SCL18: J73.4, J74.4, J75.4, R92.1, U$542.P5
SCL19: J77.4, J78.4, J79.4, R97.1, U$572.P5
SCL20: J81.4, J82.4, J83.4, R102.1, U$602.P5
SCL21: J85.4, J86.4, J87.4, R107.1, U$632.P5
SCL22: J89.4, J90.4, J91.4, R112.1, U$662.P5
SCL23: J93.4, J94.4, J95.4, R117.1, U$692.P5
SDA: J4.3, J5.3, J6.3, R3.1, U$1.P6
SDA1: J2.3, J3.3, J7.3, R4.1, U$32.P6
SDA2: J9.3, J10.3, J11.3, R11.1, U$62.P6
SDA3: J13.3, J14.3, J15.3, R16.1, U$92.P6
SDA4: J17.3, J18.3, J19.3, R21.1, U$122.P6
SDA5: J21.3, J22.3, J23.3, R26.1, U$152.P6
SDA6: J25.3, J26.3, J27.3, R31.1, U$182.P6
SDA7: J29.3, J30.3, J31.3, R36.1, U$212.P6
SDA8: J33.3, J34.3, J35.3, R41.1, U$242.P6
SDA9: J37.3, J38.3, J39.3, R46.1, U$272.P6
SDA10: J41.3, J42.3, J43.3, R51.1, U$302.P6
SDA11: J45.3, J46.3, J47.3, R56.1, U$332.P6
SDA12: J49.3, J50.3, J51.3, R61.1, U$362.P6
SDA13: J53.3, J54.3, J55.3, R66.1, U$392.P6
SDA14: J57.3, J58.3, J59.3, R71.1, U$422.P6
SDA15: J61.3, J62.3, J63.3, R76.1, U$452.P6
SDA16: J65.3, J66.3, J67.3, R81.1, U$482.P6
SDA17: J69.3, J70.3, J71.3, R86.1, U$512.P6
SDA18: J73.3, J74.3, J75.3, R91.1, U$542.P6
SDA19: J77.3, J78.3, J79.3, R96.1, U$572.P6
SDA20: J81.3, J82.3, J83.3, R101.1, U$602.P6
SDA21: J85.3, J86.3, J87.3, R106.1, U$632.P6
SDA22: J89.3, J90.3, J91.3, R111.1, U$662.P6
SDA23: J93.3, J94.3, J95.3, R116.1, U$692.P6

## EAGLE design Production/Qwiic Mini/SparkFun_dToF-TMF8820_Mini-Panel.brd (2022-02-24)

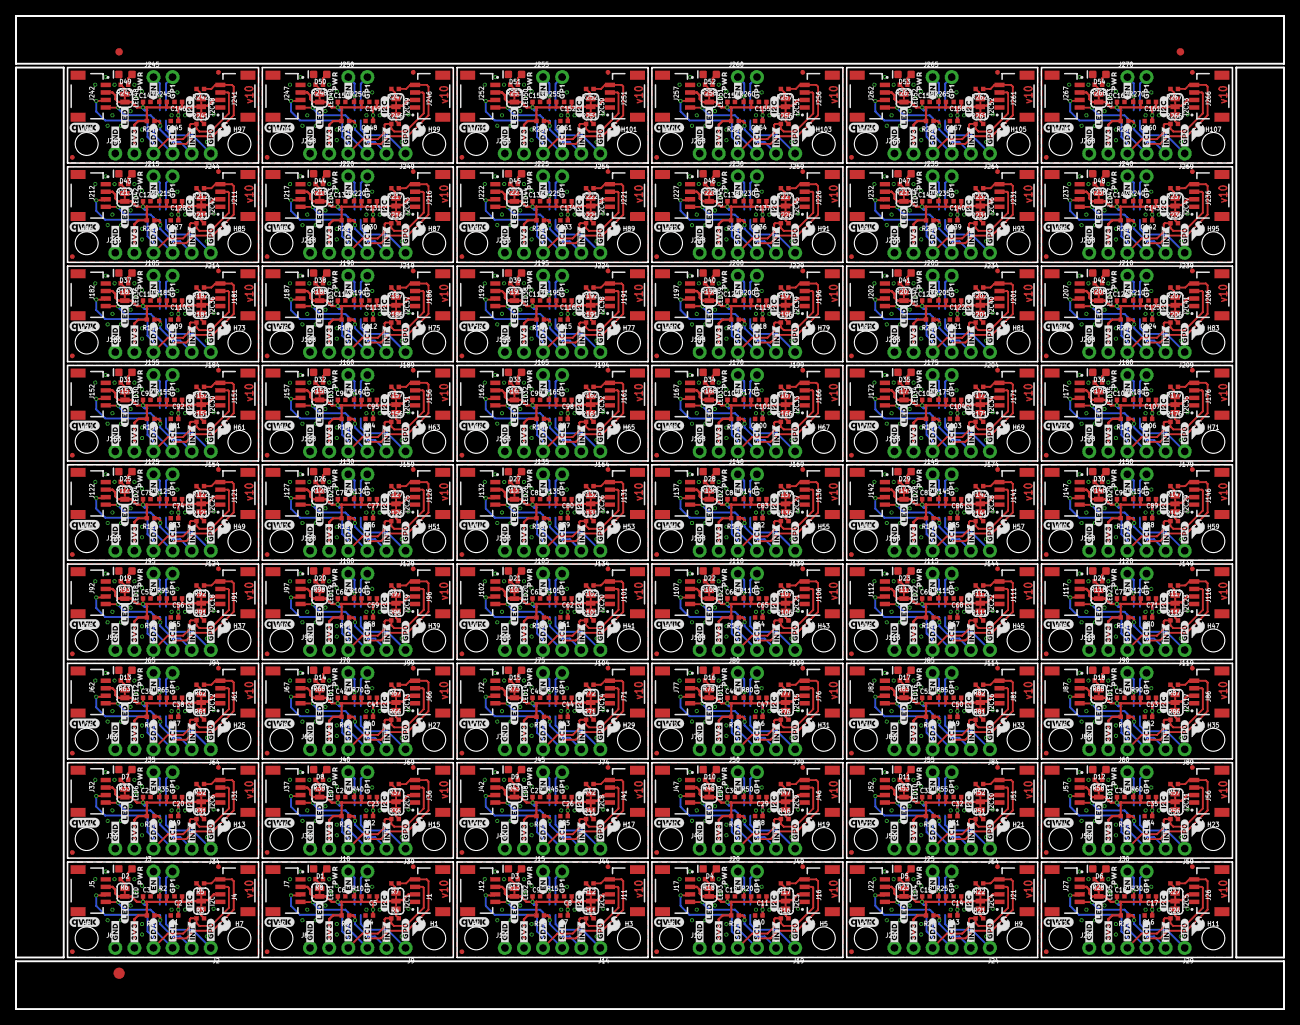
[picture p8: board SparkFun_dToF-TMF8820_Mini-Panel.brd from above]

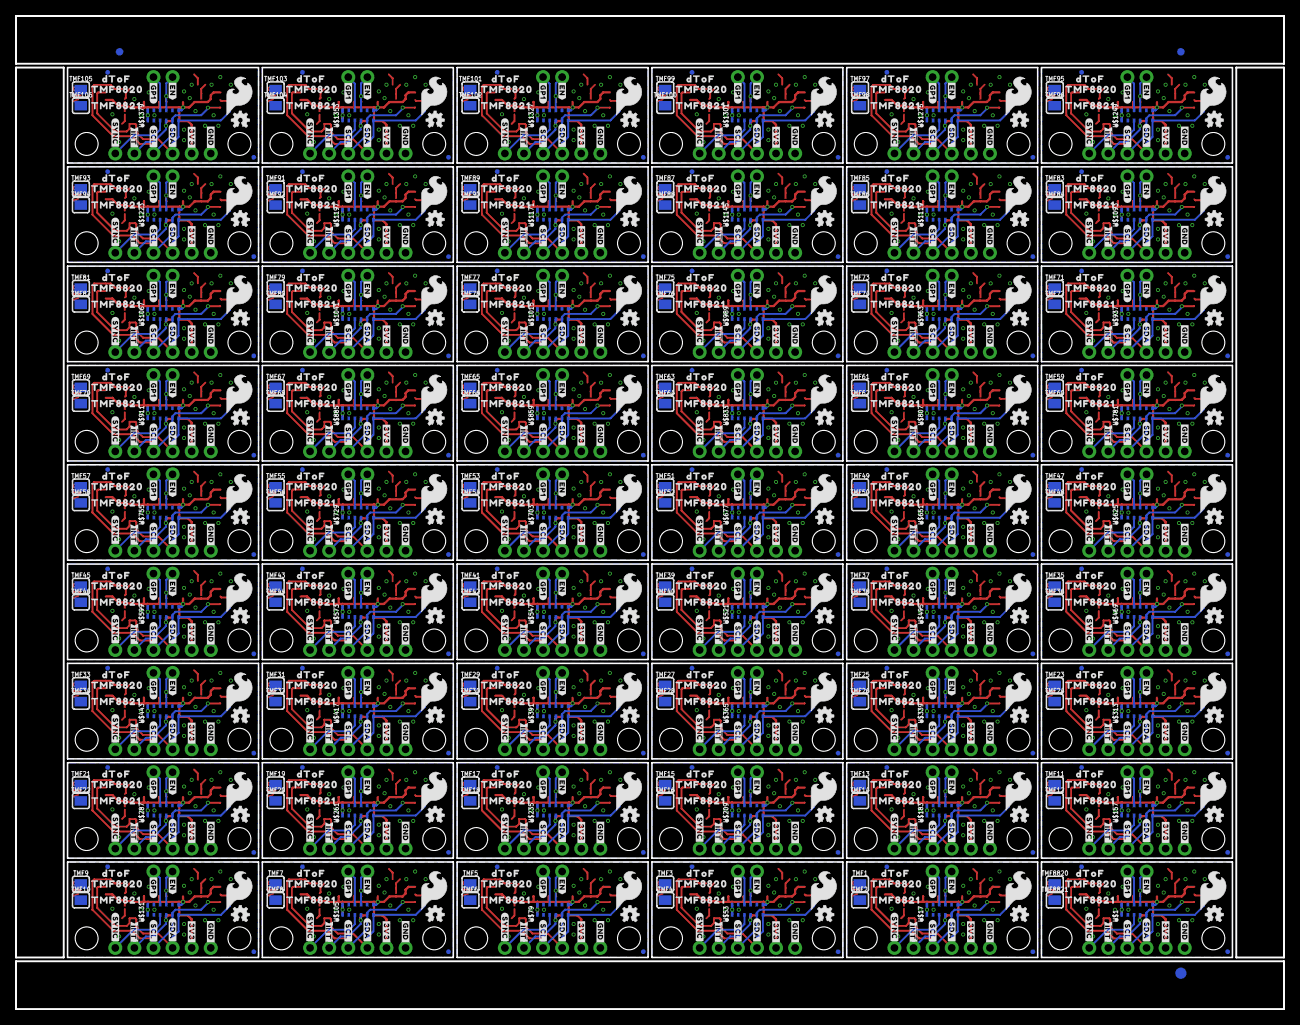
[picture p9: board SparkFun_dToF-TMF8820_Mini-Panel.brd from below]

Board: 2 copper layers, 168.7 x 132.1 mm, 2922 parts (975 on the bottom side), 648 nets.

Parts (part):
C1, C2, C3, C4, C5, C6, C7, C8, C9, C10, C11, C12, C13, C14, C15, C16, C17, C18, C19, C20, C21, C22, C23, C24, C25, C26, C27, C28, C29, C30, C31, C32, C33, C34, C35, C36, C37, C38, C39, C40, C41, C42, C43, C44, C45, C46, C47, C48, C49, C50, C51, C52, C53, C54, C55, C56, C57, C58, C59, C60, C61, C62, C63, C64, C65, C66, C67, C68, C69, C70, C71, C72, C73, C74, C75, C76, C77, C78, C79, C80, C81, C82, C83, C84, C85, C86, C87, C88, C89, C90, C91, C92, C93, C94, C95, C96, C97, C98, C99, C100, C101, C102, C103, C104, C105, C106, C107, C108, C109, C110, C111, C112, C113, C114, C115, C116, C117, C118, C119, C120, C121, C122, C123, C124, C125, C126, C127, C128, C129, C130, C131, C132, C133, C134, C135, C136, C137, C138, C139, C140, C141, C142, C143, C144, C145, C146, C147, C148, C149, C150, C151, C152, C153, C154, C155, C156, C157, C158, C159, C160, C161, C162: 0.1uF; 0402-TIGHT
D1, D2, D3, D4, D5, D6, D7, D8, D9, D10, D11, D12, D13, D14, D15, D16, D17, D18, D19, D20, D21, D22, D23, D24, D25, D26, D27, D28, D29, D30, D31, D32, D33, D34, D35, D36, D37, D38, D39, D40, D41, D42, D43, D44, D45, D46, D47, D48, D49, D50, D51, D52, D53, D54: RED; LED-0603
E$1, E$2, E$3, E$4: FIDUCIAL-1X2
E$5, E$6: FIDUCIAL-1.5X3
FD1, FD2, FD3, FD4, FD5, FD6, FD7, FD8, FD9, FD10, FD11, FD12, FD13, FD14, FD15, FD16, FD17, FD18, FD19, FD20, FD21, FD22, FD23, FD24, FD25, FD26, FD27, FD28, FD29, FD30, FD31, FD32, FD33, FD34, FD35, FD36, FD37, FD38, FD39, FD40, FD41, FD42, FD43, FD44, FD45, FD46, FD47, FD48, FD49, FD50, FD51, FD52, FD53, FD54, FD55, FD56, FD57, FD58, FD59, FD60, FD61, FD62, FD63, FD64, FD65, FD66, FD67, FD68, FD69, FD70, FD71, FD72, FD73, FD74, FD75, FD76, FD77, FD78, FD79, FD80, FD81, FD82, FD83, FD84, FD85, FD86, FD87, FD88, FD89, FD90, FD91, FD92, FD93, FD94, FD95, FD96, FD97, FD98, FD99, FD100, FD101, FD102, FD103, FD104, FD105, FD106, FD107, FD108, FD109, FD110, FD111, FD112, FD113, FD114, FD115, FD116, FD117, FD118, FD119, FD120, FD121, FD122, FD123, FD124, FD125, FD126, FD127, FD128, FD129, FD130, FD131, FD132, FD133, FD134, FD135, FD136, FD137, FD138, FD139, FD140, FD141, FD142, FD143, FD144, FD145, FD146, FD147, FD148, FD149, FD150, FD151, FD152, FD153, FD154, FD155, FD156, FD157, FD158, FD159, FD160, FD161, FD162, FD163, FD164, FD165, FD166, FD167, FD168, FD169, FD170, FD171, FD172, FD173, FD174, FD175, FD176, FD177, FD178, FD179, FD180, FD181, FD182, FD183, FD184, FD185, FD186, FD187, FD188, FD189, FD190, FD191, FD192, FD193, FD194, FD195, FD196, FD197, FD198, FD199, FD200, FD201, FD202, FD203, FD204, FD205, FD206, FD207, FD208, FD209, FD210, FD211, FD212, FD213, FD214, FD215, FD216: FIDUCIALUFIDUCIAL; FIDUCIAL-MICRO
FRAME1, FRAME2, FRAME3, FRAME4, FRAME5, FRAME6, FRAME7, FRAME8, FRAME9, FRAME10, FRAME11, FRAME12, FRAME13, FRAME14, FRAME15, FRAME16, FRAME17, FRAME18, FRAME19, FRAME20, FRAME21, FRAME22, FRAME23, FRAME24, FRAME25, FRAME26, FRAME27, FRAME28, FRAME29, FRAME30, FRAME31, FRAME32, FRAME33, FRAME34, FRAME35, FRAME36, FRAME37, FRAME38, FRAME39, FRAME40, FRAME41, FRAME42, FRAME43, FRAME44, FRAME45, FRAME46, FRAME47, FRAME48, FRAME49, FRAME50, FRAME51, FRAME52, FRAME53, FRAME54: FRAME-LETTER; CREATIVE_COMMONS
H1, H2, H3, H4, H5, H6, H7, H8, H9, H10, H11, H12, H13, H14, H15, H16, H17, H18, H19, H20, H21, H22, H23, H24, H25, H26, H27, H28, H29, H30, H31, H32, H33, H34, H35, H36, H37, H38, H39, H40, H41, H42, H43, H44, H45, H46, H47, H48, H49, H50, H51, H52, H53, H54, H55, H56, H57, H58, H59, H60, H61, H62, H63, H64, H65, H66, H67, H68, H69, H70, H71, H72, H73, H74, H75, H76, H77, H78, H79, H80, H81, H82, H83, H84, H85, H86, H87, H88, H89, H90, H91, H92, H93, H94, H95, H96, H97, H98, H99, H100, H101, H102, H103, H104, H105, H106, H107, H108: STAND-OFFTIGHT; STAND-OFF-TIGHT
I2C, I2C1, I2C2, I2C3, I2C4, I2C5, I2C6, I2C7, I2C8, I2C9, I2C10, I2C11, I2C12, I2C13, I2C14, I2C15, I2C16, I2C17, I2C18, I2C19, I2C20, I2C21, I2C22, I2C23, I2C24, I2C25, I2C26, I2C27, I2C28, I2C29, I2C30, I2C31, I2C32, I2C33, I2C34, I2C35, I2C36, I2C37, I2C38, I2C39, I2C40, I2C41, I2C42, I2C43, I2C44, I2C45, I2C46, I2C47, I2C48, I2C49, I2C50, I2C51, I2C52, I2C53: I2C_PU; SMT-JUMPER_3_2-NC_TRACE_SILK
J1, J4, J5, J7, J11, J12, J16, J17, J21, J22, J26, J27, J31, J32, J36, J37, J41, J42, J46, J47, J51, J52, J56, J57, J61, J62, J66, J67, J71, J72, J76, J77, J81, J82, J86, J87, J91, J92, J96, J97, J101, J102, J106, J107, J111, J112, J116, J117, J121, J122, J126, J127, J131, J132, J136, J137, J141, J142, J146, J147, J151, J152, J156, J157, J161, J162, J166, J167, J171, J172, J176, J177, J181, J182, J186, J187, J191, J192, J196, J197, J201, J202, J206, J207, J211, J212, J216, J217, J221, J222, J226, J227, J231, J232, J236, J237, J241, J242, J246, J247, J251, J252, J256, J257, J261, J262, J266, J267: QWIIC_RIGHT_ANGLE; JST04_1MM_RA
J2, J3, J9, J10, J14, J15, J19, J20, J24, J25, J29, J30, J34, J35, J39, J40, J44, J45, J49, J50, J54, J55, J59, J60, J64, J65, J69, J70, J74, J75, J79, J80, J84, J85, J89, J90, J94, J95, J99, J100, J104, J105, J109, J110, J114, J115, J119, J120, J124, J125, J129, J130, J134, J135, J139, J140, J144, J145, J149, J150, J154, J155, J159, J160, J164, J165, J169, J170, J174, J175, J179, J180, J184, J185, J189, J190, J194, J195, J199, J200, J204, J205, J209, J210, J214, J215, J219, J220, J224, J225, J229, J230, J234, J235, J239, J240, J244, J245, J249, J250, J254, J255, J259, J260, J264, J265, J269, J270: 1X02_NO_SILK
J6, J8, J13, J18, J23, J28, J33, J38, J43, J48, J53, J58, J63, J68, J73, J78, J83, J88, J93, J98, J103, J108, J113, J118, J123, J128, J133, J138, J143, J148, J153, J158, J163, J168, J173, J178, J183, J188, J193, J198, J203, J208, J213, J218, J223, J228, J233, J238, J243, J248, J253, J258, J263, J268: 1X04_NO_SILK
LED, LED1, LED2, LED3, LED4, LED5, LED6, LED7, LED8, LED9, LED10, LED11, LED12, LED13, LED14, LED15, LED16, LED17, LED18, LED19, LED20, LED21, LED22, LED23, LED24, LED25, LED26, LED27, LED28, LED29, LED30, LED31, LED32, LED33, LED34, LED35, LED36, LED37, LED38, LED39, LED40, LED41, LED42, LED43, LED44, LED45, LED46, LED47, LED48, LED49, LED50, LED51, LED52, LED53: LED; SMT-JUMPER_2_NC_TRACE_SILK
LOGO1, LOGO4, LOGO7, LOGO10, LOGO13, LOGO16, LOGO19, LOGO22, LOGO25, LOGO28, LOGO31, LOGO34, LOGO37, LOGO40, LOGO43, LOGO46, LOGO49, LOGO52, LOGO55, LOGO58, LOGO61, LOGO64, LOGO67, LOGO70, LOGO73, LOGO76, LOGO79, LOGO82, LOGO85, LOGO88, LOGO91, LOGO94, LOGO97, LOGO100, LOGO103, LOGO106, LOGO109, LOGO112, LOGO115, LOGO118, LOGO121, LOGO124, LOGO127, LOGO130, LOGO133, LOGO136, LOGO139, LOGO142, LOGO145, LOGO148, LOGO151, LOGO154, LOGO157, LOGO160: SFE_LOGO_NAMEBLANK; BLANK
LOGO2, LOGO5, LOGO8, LOGO11, LOGO14, LOGO17, LOGO20, LOGO23, LOGO26, LOGO29, LOGO32, LOGO35, LOGO38, LOGO41, LOGO44, LOGO47, LOGO50, LOGO53, LOGO56, LOGO59, LOGO62, LOGO65, LOGO68, LOGO71, LOGO74, LOGO77, LOGO80, LOGO83, LOGO86, LOGO89, LOGO92, LOGO95, LOGO98, LOGO101, LOGO104, LOGO107, LOGO110, LOGO113, LOGO116, LOGO119, LOGO122, LOGO125, LOGO128, LOGO131, LOGO134, LOGO137, LOGO140, LOGO143, LOGO146, LOGO149, LOGO152, LOGO155, LOGO158, LOGO161: QWIIC_LOGO_4MM; QWIIC_4MM
LOGO3, LOGO6, LOGO9, LOGO12, LOGO15, LOGO18, LOGO21, LOGO24, LOGO27, LOGO30, LOGO33, LOGO36, LOGO39, LOGO42, LOGO45, LOGO48, LOGO51, LOGO54, LOGO57, LOGO60, LOGO63, LOGO66, LOGO69, LOGO72, LOGO75, LOGO78, LOGO81, LOGO84, LOGO87, LOGO90, LOGO93, LOGO96, LOGO99, LOGO102, LOGO105, LOGO108, LOGO111, LOGO114, LOGO117, LOGO120, LOGO123, LOGO126, LOGO129, LOGO132, LOGO135, LOGO138, LOGO141, LOGO144, LOGO147, LOGO150, LOGO153, LOGO156, LOGO159, LOGO162: OSHW-LOGONO_SILK; DUMMY
R1, R2, R9, R10, R14, R15, R19, R20, R24, R25, R29, R30, R34, R35, R39, R40, R44, R45, R49, R50, R54, R55, R59, R60, R64, R65, R69, R70, R74, R75, R79, R80, R84, R85, R89, R90, R94, R95, R99, R100, R104, R105, R109, R110, R114, R115, R119, R120, R124, R125, R129, R130, R134, R135, R139, R140, R144, R145, R149, R150, R154, R155, R159, R160, R164, R165, R169, R170, R174, R175, R179, R180, R184, R185, R189, R190, R194, R195, R199, R200, R204, R205, R209, R210, R214, R215, R219, R220, R224, R225, R229, R230, R234, R235, R239, R240, R244, R245, R249, R250, R254, R255, R259, R260, R264, R265, R269, R270: 10k; 0402-TIGHT
R3, R4, R5, R7, R11, R12, R16, R17, R21, R22, R26, R27, R31, R32, R36, R37, R41, R42, R46, R47, R51, R52, R56, R57, R61, R62, R66, R67, R71, R72, R76, R77, R81, R82, R86, R87, R91, R92, R96, R97, R101, R102, R106, R107, R111, R112, R116, R117, R121, R122, R126, R127, R131, R132, R136, R137, R141, R142, R146, R147, R151, R152, R156, R157, R161, R162, R166, R167, R171, R172, R176, R177, R181, R182, R186, R187, R191, R192, R196, R197, R201, R202, R206, R207, R211, R212, R216, R217, R221, R222, R226, R227, R231, R232, R236, R237, R241, R242, R246, R247, R251, R252, R256, R257, R261, R262, R266, R267: 2.2k; 0402-TIGHT
R6, R8, R13, R18, R23, R28, R33, R38, R43, R48, R53, R58, R63, R68, R73, R78, R83, R88, R93, R98, R103, R108, R113, R118, R123, R128, R133, R138, R143, R148, R153, R158, R163, R168, R173, R178, R183, R188, R193, R198, R203, R208, R213, R218, R223, R228, R233, R238, R243, R248, R253, R258, R263, R268: 1k; 0402-TIGHT
TMF1, TMF3, TMF5, TMF7, TMF9, TMF11, TMF13, TMF15, TMF17, TMF19, TMF21, TMF23, TMF25, TMF27, TMF29, TMF31, TMF33, TMF35, TMF37, TMF39, TMF41, TMF43, TMF45, TMF47, TMF49, TMF51, TMF53, TMF55, TMF57, TMF59, TMF61, TMF63, TMF65, TMF67, TMF69, TMF71, TMF73, TMF75, TMF77, TMF79, TMF81, TMF83, TMF85, TMF87, TMF89, TMF91, TMF93, TMF95, TMF97, TMF99, TMF101, TMF103, TMF105, TMF8820: PROD_ID_PASTE_SILK; PRODUCT_IDENT_PASTE_SILK
TMF2, TMF4, TMF6, TMF8, TMF10, TMF12, TMF14, TMF16, TMF18, TMF20, TMF22, TMF24, TMF26, TMF28, TMF30, TMF32, TMF34, TMF36, TMF38, TMF40, TMF42, TMF44, TMF46, TMF48, TMF50, TMF52, TMF54, TMF56, TMF58, TMF60, TMF62, TMF64, TMF66, TMF68, TMF70, TMF72, TMF74, TMF76, TMF78, TMF80, TMF82, TMF84, TMF86, TMF88, TMF90, TMF92, TMF94, TMF96, TMF98, TMF100, TMF102, TMF104, TMF106, TMF8821: PROD_ID_NO-PASTE_SILK; PRODUCT_IDENT_NO_SILK
U$1, U$17, U$53, U$79, U$105, U$131, U$157, U$183, U$209, U$235, U$261, U$287, U$313, U$339, U$365, U$391, U$417, U$443, U$469, U$495, U$521, U$547, U$573, U$599, U$625, U$651, U$677, U$703, U$729, U$755, U$781, U$807, U$833, U$859, U$885, U$911, U$937, U$963, U$989, U$1015, U$1041, U$1067, U$1093, U$1119, U$1145, U$1171, U$1197, U$1223, U$1249, U$1275, U$1301, U$1327, U$1353, U$1379: TMF882X_TMF8820; TMF882X
U$2, U$49, U$75, U$101, U$127, U$153, U$179, U$205, U$231, U$257, U$283, U$309, U$335, U$361, U$387, U$413, U$439, U$465, U$491, U$517, U$543, U$569, U$595, U$621, U$647, U$673, U$699, U$725, U$751, U$777, U$803, U$829, U$855, U$881, U$907, U$933, U$959, U$985, U$1011, U$1037, U$1063, U$1089, U$1115, U$1141, U$1167, U$1193, U$1219, U$1245, U$1271, U$1297, U$1323, U$1349, U$1375, U$1401: #GP1#8
U$3, U$34, U$66, U$92, U$118, U$144, U$170, U$196, U$222, U$248, U$274, U$300, U$326, U$352, U$378, U$404, U$430, U$456, U$482, U$508, U$534, U$560, U$586, U$612, U$638, U$664, U$690, U$716, U$742, U$768, U$794, U$820, U$846, U$872, U$898, U$924, U$950, U$976, U$1002, U$1028, U$1054, U$1080, U$1106, U$1132, U$1158, U$1184, U$1210, U$1236, U$1262, U$1288, U$1314, U$1340, U$1366, U$1392: ##INT##9
U$4, U$36, U$67, U$93, U$119, U$145, U$171, U$197, U$223, U$249, U$275, U$301, U$327, U$353, U$379, U$405, U$431, U$457, U$483, U$509, U$535, U$561, U$587, U$613, U$639, U$665, U$691, U$717, U$743, U$769, U$795, U$821, U$847, U$873, U$899, U$925, U$951, U$977, U$1003, U$1029, U$1055, U$1081, U$1107, U$1133, U$1159, U$1185, U$1211, U$1237, U$1263, U$1289, U$1315, U$1341, U$1367, U$1393: ##INT##8
U$5, U$41, U$68, U$94, U$120, U$146, U$172, U$198, U$224, U$250, U$276, U$302, U$328, U$354, U$380, U$406, U$432, U$458, U$484, U$510, U$536, U$562, U$588, U$614, U$640, U$666, U$692, U$718, U$744, U$770, U$796, U$822, U$848, U$874, U$900, U$926, U$952, U$978, U$1004, U$1030, U$1056, U$1082, U$1108, U$1134, U$1160, U$1186, U$1212, U$1238, U$1264, U$1290, U$1316, U$1342, U$1368, U$1394: #SYNC#8
U$6, U$50, U$76, U$102, U$128, U$154, U$180, U$206, U$232, U$258, U$284, U$310, U$336, U$362, U$388, U$414, U$440, U$466, U$492, U$518, U$544, U$570, U$596, U$622, U$648, U$674, U$700, U$726, U$752, U$778, U$804, U$830, U$856, U$882, U$908, U$934, U$960, U$986, U$1012, U$1038, U$1064, U$1090, U$1116, U$1142, U$1168, U$1194, U$1220, U$1246, U$1272, U$1298, U$1324, U$1350, U$1376, U$1402: GP18
U$7, U$42, U$69, U$95, U$121, U$147, U$173, U$199, U$225, U$251, U$277, U$303, U$329, U$355, U$381, U$407, U$433, U$459, U$485, U$511, U$537, U$563, U$589, U$615, U$641, U$667, U$693, U$719, U$745, U$771, U$797, U$823, U$849, U$875, U$901, U$927, U$953, U$979, U$1005, U$1031, U$1057, U$1083, U$1109, U$1135, U$1161, U$1187, U$1213, U$1239, U$1265, U$1291, U$1317, U$1343, U$1369, U$1395: DTOF882188211
U$8, U$44, U$70, U$96, U$122, U$148, U$174, U$200, U$226, U$252, U$278, U$304, U$330, U$356, U$382, U$408, U$434, U$460, U$486, U$512, U$538, U$564, U$590, U$616, U$642, U$668, U$694, U$720, U$746, U$772, U$798, U$824, U$850, U$876, U$902, U$928, U$954, U$980, U$1006, U$1032, U$1058, U$1084, U$1110, U$1136, U$1162, U$1188, U$1214, U$1240, U$1266, U$1292, U$1318, U$1344, U$1370, U$1396: TMF88209
U$9, U$21, U$31, U$45, U$54, U$71, U$80, U$97, U$106, U$123, U$132, U$149, U$158, U$175, U$184, U$201, U$210, U$227, U$236, U$253, U$262, U$279, U$288, U$305, U$314, U$331, U$340, U$357, U$366, U$383, U$392, U$409, U$418, U$435, U$444, U$461, U$470, U$487, U$496, U$513, U$522, U$539, U$548, U$565, U$574, U$591, U$600, U$617, U$626, U$643, U$652, U$669, U$678, U$695, U$704, U$721, U$730, U$747, U$756, U$773, U$782, U$799, U$808, U$825, U$834, U$851, U$860, U$877, U$886, U$903, U$912, U$929, U$938, U$955, U$964, U$981, U$990, U$1007, U$1016, U$1033, U$1042, U$1059, U$1068, U$1085, U$1094, U$1111, U$1120, U$1137, U$1146, U$1163, U$1172, U$1189, U$1198, U$1215, U$1224, U$1241, U$1250, U$1267, U$1276, U$1293, U$1302, U$1319, U$1328, U$1345, U$1354, U$1371, U$1380, U$1397: #EN#7
U$10, U$22, U$28, U$37, U$55, U$61, U$81, U$87, U$107, U$113, U$133, U$139, U$159, U$165, U$185, U$191, U$211, U$217, U$237, U$243, U$263, U$269, U$289, U$295, U$315, U$321, U$341, U$347, U$367, U$373, U$393, U$399, U$419, U$425, U$445, U$451, U$471, U$477, U$497, U$503, U$523, U$529, U$549, U$555, U$575, U$581, U$601, U$607, U$627, U$633, U$653, U$659, U$679, U$685, U$705, U$711, U$731, U$737, U$757, U$763, U$783, U$789, U$809, U$815, U$835, U$841, U$861, U$867, U$887, U$893, U$913, U$919, U$939, U$945, U$965, U$971, U$991, U$997, U$1017, U$1023, U$1043, U$1049, U$1069, U$1075, U$1095, U$1101, U$1121, U$1127, U$1147, U$1153, U$1173, U$1179, U$1199, U$1205, U$1225, U$1231, U$1251, U$1257, U$1277, U$1283, U$1303, U$1309, U$1329, U$1335, U$1355, U$1361, U$1381, U$1387: #3V3#0
U$11, U$46, U$72, U$98, U$124, U$150, U$176, U$202, U$228, U$254, U$280, U$306, U$332, U$358, U$384, U$410, U$436, U$462, U$488, U$514, U$540, U$566, U$592, U$618, U$644, U$670, U$696, U$722, U$748, U$774, U$800, U$826, U$852, U$878, U$904, U$930, U$956, U$982, U$1008, U$1034, U$1060, U$1086, U$1112, U$1138, U$1164, U$1190, U$1216, U$1242, U$1268, U$1294, U$1320, U$1346, U$1372, U$1398: TMF882188210
U$12, U$51, U$77, U$103, U$129, U$155, U$181, U$207, U$233, U$259, U$285, U$311, U$337, U$363, U$389, U$415, U$441, U$467, U$493, U$519, U$545, U$571, U$597, U$623, U$649, U$675, U$701, U$727, U$753, U$779, U$805, U$831, U$857, U$883, U$909, U$935, U$961, U$987, U$1013, U$1039, U$1065, U$1091, U$1117, U$1143, U$1169, U$1195, U$1221, U$1247, U$1273, U$1299, U$1325, U$1351, U$1377, U$1403: SFE_LOGO_FLAME_.2
U$13, U$47, U$73, U$99, U$125, U$151, U$177, U$203, U$229, U$255, U$281, U$307, U$333, U$359, U$385, U$411, U$437, U$463, U$489, U$515, U$541, U$567, U$593, U$619, U$645, U$671, U$697, U$723, U$749, U$775, U$801, U$827, U$853, U$879, U$905, U$931, U$957, U$983, U$1009, U$1035, U$1061, U$1087, U$1113, U$1139, U$1165, U$1191, U$1217, U$1243, U$1269, U$1295, U$1321, U$1347, U$1373, U$1399: #LED#10
U$14, U$48, U$74, U$100, U$126, U$152, U$178, U$204, U$230, U$256, U$282, U$308, U$334, U$360, U$386, U$412, U$438, U$464, U$490, U$516, U$542, U$568, U$594, U$620, U$646, U$672, U$698, U$724, U$750, U$776, U$802, U$828, U$854, U$880, U$906, U$932, U$958, U$984, U$1010, U$1036, U$1062, U$1088, U$1114, U$1140, U$1166, U$1192, U$1218, U$1244, U$1270, U$1296, U$1322, U$1348, U$1374, U$1400: #GP0#19
U$15, U$52, U$78, U$104, U$130, U$156, U$182, U$208, U$234, U$260, U$286, U$312, U$338, U$364, U$390, U$416, U$442, U$468, U$494, U$520, U$546, U$572, U$598, U$624, U$650, U$676, U$702, U$728, U$754, U$780, U$806, U$832, U$858, U$884, U$910, U$936, U$962, U$988, U$1014, U$1040, U$1066, U$1092, U$1118, U$1144, U$1170, U$1196, U$1222, U$1248, U$1274, U$1300, U$1326, U$1352, U$1378, U$1404: OSHW-LOGO-MINI
U$16, U$23, U$29, U$38, U$56, U$62, U$82, U$88, U$108, U$114, U$134, U$140, U$160, U$166, U$186, U$192, U$212, U$218, U$238, U$244, U$264, U$270, U$290, U$296, U$316, U$322, U$342, U$348, U$368, U$374, U$394, U$400, U$420, U$426, U$446, U$452, U$472, U$478, U$498, U$504, U$524, U$530, U$550, U$556, U$576, U$582, U$602, U$608, U$628, U$634, U$654, U$660, U$680, U$686, U$706, U$712, U$732, U$738, U$758, U$764, U$784, U$790, U$810, U$816, U$836, U$842, U$862, U$868, U$888, U$894, U$914, U$920, U$940, U$946, U$966, U$972, U$992, U$998, U$1018, U$1024, U$1044, U$1050, U$1070, U$1076, U$1096, U$1102, U$1122, U$1128, U$1148, U$1154, U$1174, U$1180, U$1200, U$1206, U$1226, U$1232, U$1252, U$1258, U$1278, U$1284, U$1304, U$1310, U$1330, U$1336, U$1356, U$1362, U$1382, U$1388: #GND#4
U$18, U$24, U$32, U$40, U$57, U$64, U$83, U$90, U$109, U$116, U$135, U$142, U$161, U$168, U$187, U$194, U$213, U$220, U$239, U$246, U$265, U$272, U$291, U$298, U$317, U$324, U$343, U$350, U$369, U$376, U$395, U$402, U$421, U$428, U$447, U$454, U$473, U$480, U$499, U$506, U$525, U$532, U$551, U$558, U$577, U$584, U$603, U$610, U$629, U$636, U$655, U$662, U$681, U$688, U$707, U$714, U$733, U$740, U$759, U$766, U$785, U$792, U$811, U$818, U$837, U$844, U$863, U$870, U$889, U$896, U$915, U$922, U$941, U$948, U$967, U$974, U$993, U$1000, U$1019, U$1026, U$1045, U$1052, U$1071, U$1078, U$1097, U$1104, U$1123, U$1130, U$1149, U$1156, U$1175, U$1182, U$1201, U$1208, U$1227, U$1234, U$1253, U$1260, U$1279, U$1286, U$1305, U$1312, U$1331, U$1338, U$1357, U$1364, U$1383, U$1390: #SDA#6
U$19, U$25, U$30, U$39, U$58, U$63, U$84, U$89, U$110, U$115, U$136, U$141, U$162, U$167, U$188, U$193, U$214, U$219, U$240, U$245, U$266, U$271, U$292, U$297, U$318, U$323, U$344, U$349, U$370, U$375, U$396, U$401, U$422, U$427, U$448, U$453, U$474, U$479, U$500, U$505, U$526, U$531, U$552, U$557, U$578, U$583, U$604, U$609, U$630, U$635, U$656, U$661, U$682, U$687, U$708, U$713, U$734, U$739, U$760, U$765, U$786, U$791, U$812, U$817, U$838, U$843, U$864, U$869, U$890, U$895, U$916, U$921, U$942, U$947, U$968, U$973, U$994, U$999, U$1020, U$1025, U$1046, U$1051, U$1072, U$1077, U$1098, U$1103, U$1124, U$1129, U$1150, U$1155, U$1176, U$1181, U$1202, U$1207, U$1228, U$1233, U$1254, U$1259, U$1280, U$1285, U$1306, U$1311, U$1332, U$1337, U$1358, U$1363, U$1384, U$1389: #SCL#5
U$20, U$26, U$59, U$85, U$111, U$137, U$163, U$189, U$215, U$241, U$267, U$293, U$319, U$345, U$371, U$397, U$423, U$449, U$475, U$501, U$527, U$553, U$579, U$605, U$631, U$657, U$683, U$709, U$735, U$761, U$787, U$813, U$839, U$865, U$891, U$917, U$943, U$969, U$995, U$1021, U$1047, U$1073, U$1099, U$1125, U$1151, U$1177, U$1203, U$1229, U$1255, U$1281, U$1307, U$1333, U$1359, U$1385: #I2C#11
U$27, U$35, U$60, U$86, U$112, U$138, U$164, U$190, U$216, U$242, U$268, U$294, U$320, U$346, U$372, U$398, U$424, U$450, U$476, U$502, U$528, U$554, U$580, U$606, U$632, U$658, U$684, U$710, U$736, U$762, U$788, U$814, U$840, U$866, U$892, U$918, U$944, U$970, U$996, U$1022, U$1048, U$1074, U$1100, U$1126, U$1152, U$1178, U$1204, U$1230, U$1256, U$1282, U$1308, U$1334, U$1360, U$1386: SFE_LOGO_FLAME_.1
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

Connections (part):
3.3V: C1.1, C2.1, C3.1, I2C.2, J4.2, J5.2, J6.2, LED.2, R1.2, R2.2, U$1.P1, U$1.P7, U$1.P12
3.3V1: C4.1, C5.1, C6.1, I2C1.2, J1.2, J7.2, J8.2, LED1.2, R9.2, R10.2, U$17.P1, U$17.P7, U$17.P12
3.3V2: C7.1, C8.1, C9.1, I2C2.2, J11.2, J12.2, J13.2, LED2.2, R14.2, R15.2, U$53.P1, U$53.P7, U$53.P12
3.3V3: C10.1, C11.1, C12.1, I2C3.2, J16.2, J17.2, J18.2, LED3.2, R19.2, R20.2, U$79.P1, U$79.P7, U$79.P12
3.3V4: C13.1, C14.1, C15.1, I2C4.2, J21.2, J22.2, J23.2, LED4.2, R24.2, R25.2, U$105.P1, U$105.P7, U$105.P12
3.3V5: C16.1, C17.1, C18.1, I2C5.2, J26.2, J27.2, J28.2, LED5.2, R29.2, R30.2, U$131.P1, U$131.P7, U$131.P12
3.3V6: C19.1, C20.1, C21.1, I2C6.2, J31.2, J32.2, J33.2, LED6.2, R34.2, R35.2, U$157.P1, U$157.P7, U$157.P12
3.3V7: C22.1, C23.1, C24.1, I2C7.2, J36.2, J37.2, J38.2, LED7.2, R39.2, R40.2, U$183.P1, U$183.P7, U$183.P12
3.3V8: C25.1, C26.1, C27.1, I2C8.2, J41.2, J42.2, J43.2, LED8.2, R44.2, R45.2, U$209.P1, U$209.P7, U$209.P12
3.3V9: C28.1, C29.1, C30.1, I2C9.2, J46.2, J47.2, J48.2, LED9.2, R49.2, R50.2, U$235.P1, U$235.P7, U$235.P12
3.3V10: C31.1, C32.1, C33.1, I2C10.2, J51.2, J52.2, J53.2, LED10.2, R54.2, R55.2, U$261.P1, U$261.P7, U$261.P12
3.3V11: C34.1, C35.1, C36.1, I2C11.2, J56.2, J57.2, J58.2, LED11.2, R59.2, R60.2, U$287.P1, U$287.P7, U$287.P12
3.3V12: C37.1, C38.1, C39.1, I2C12.2, J61.2, J62.2, J63.2, LED12.2, R64.2, R65.2, U$313.P1, U$313.P7, U$313.P12
3.3V13: C40.1, C41.1, C42.1, I2C13.2, J66.2, J67.2, J68.2, LED13.2, R69.2, R70.2, U$339.P1, U$339.P7, U$339.P12
3.3V14: C43.1, C44.1, C45.1, I2C14.2, J71.2, J72.2, J73.2, LED14.2, R74.2, R75.2, U$365.P1, U$365.P7, U$365.P12
3.3V15: C46.1, C47.1, C48.1, I2C15.2, J76.2, J77.2, J78.2, LED15.2, R79.2, R80.2, U$391.P1, U$391.P7, U$391.P12
3.3V16: C49.1, C50.1, C51.1, I2C16.2, J81.2, J82.2, J83.2, LED16.2, R84.2, R85.2, U$417.P1, U$417.P7, U$417.P12
3.3V17: C52.1, C53.1, C54.1, I2C17.2, J86.2, J87.2, J88.2, LED17.2, R89.2, R90.2, U$443.P1, U$443.P7, U$443.P12
3.3V18: C55.1, C56.1, C57.1, I2C18.2, J91.2, J92.2, J93.2, LED18.2, R94.2, R95.2, U$469.P1, U$469.P7, U$469.P12
3.3V19: C58.1, C59.1, C60.1, I2C19.2, J96.2, J97.2, J98.2, LED19.2, R99.2, R100.2, U$495.P1, U$495.P7, U$495.P12
3.3V20: C61.1, C62.1, C63.1, I2C20.2, J101.2, J102.2, J103.2, LED20.2, R104.2, R105.2, U$521.P1, U$521.P7, U$521.P12
3.3V21: C64.1, C65.1, C66.1, I2C21.2, J106.2, J107.2, J108.2, LED21.2, R109.2, R110.2, U$547.P1, U$547.P7, U$547.P12
3.3V22: C67.1, C68.1, C69.1, I2C22.2, J111.2, J112.2, J113.2, LED22.2, R114.2, R115.2, U$573.P1, U$573.P7, U$573.P12
3.3V23: C70.1, C71.1, C72.1, I2C23.2, J116.2, J117.2, J118.2, LED23.2, R119.2, R120.2, U$599.P1, U$599.P7, U$599.P12
3.3V24: C73.1, C74.1, C75.1, I2C24.2, J121.2, J122.2, J123.2, LED24.2, R124.2, R125.2, U$625.P1, U$625.P7, U$625.P12
3.3V25: C76.1, C77.1, C78.1, I2C25.2, J126.2, J127.2, J128.2, LED25.2, R129.2, R130.2, U$651.P1, U$651.P7, U$651.P12
3.3V26: C79.1, C80.1, C81.1, I2C26.2, J131.2, J132.2, J133.2, LED26.2, R134.2, R135.2, U$677.P1, U$677.P7, U$677.P12
3.3V27: C82.1, C83.1, C84.1, I2C27.2, J136.2, J137.2, J138.2, LED27.2, R139.2, R140.2, U$703.P1, U$703.P7, U$703.P12
3.3V28: C85.1, C86.1, C87.1, I2C28.2, J141.2, J142.2, J143.2, LED28.2, R144.2, R145.2, U$729.P1, U$729.P7, U$729.P12
3.3V29: C88.1, C89.1, C90.1, I2C29.2, J146.2, J147.2, J148.2, LED29.2, R149.2, R150.2, U$755.P1, U$755.P7, U$755.P12
3.3V30: C91.1, C92.1, C93.1, I2C30.2, J151.2, J152.2, J153.2, LED30.2, R154.2, R155.2, U$781.P1, U$781.P7, U$781.P12
3.3V31: C94.1, C95.1, C96.1, I2C31.2, J156.2, J157.2, J158.2, LED31.2, R159.2, R160.2, U$807.P1, U$807.P7, U$807.P12
3.3V32: C97.1, C98.1, C99.1, I2C32.2, J161.2, J162.2, J163.2, LED32.2, R164.2, R165.2, U$833.P1, U$833.P7, U$833.P12
3.3V33: C100.1, C101.1, C102.1, I2C33.2, J166.2, J167.2, J168.2, LED33.2, R169.2, R170.2, U$859.P1, U$859.P7, U$859.P12
3.3V34: C103.1, C104.1, C105.1, I2C34.2, J171.2, J172.2, J173.2, LED34.2, R174.2, R175.2, U$885.P1, U$885.P7, U$885.P12
3.3V35: C106.1, C107.1, C108.1, I2C35.2, J176.2, J177.2, J178.2, LED35.2, R179.2, R180.2, U$911.P1, U$911.P7, U$911.P12
3.3V36: C109.1, C110.1, C111.1, I2C36.2, J181.2, J182.2, J183.2, LED36.2, R184.2, R185.2, U$937.P1, U$937.P7, U$937.P12
3.3V37: C112.1, C113.1, C114.1, I2C37.2, J186.2, J187.2, J188.2, LED37.2, R189.2, R190.2, U$963.P1, U$963.P7, U$963.P12
3.3V38: C115.1, C116.1, C117.1, I2C38.2, J191.2, J192.2, J193.2, LED38.2, R194.2, R195.2, U$989.P1, U$989.P7, U$989.P12
3.3V39: C118.1, C119.1, C120.1, I2C39.2, J196.2, J197.2, J198.2, LED39.2, R199.2, R200.2, U$1015.P1, U$1015.P7, U$1015.P12
3.3V40: C121.1, C122.1, C123.1, I2C40.2, J201.2, J202.2, J203.2, LED40.2, R204.2, R205.2, U$1041.P1, U$1041.P7, U$1041.P12
3.3V41: C124.1, C125.1, C126.1, I2C41.2, J206.2, J207.2, J208.2, LED41.2, R209.2, R210.2, U$1067.P1, U$1067.P7, U$1067.P12
3.3V42: C127.1, C128.1, C129.1, I2C42.2, J211.2, J212.2, J213.2, LED42.2, R214.2, R215.2, U$1093.P1, U$1093.P7, U$1093.P12
3.3V43: C130.1, C131.1, C132.1, I2C43.2, J216.2, J217.2, J218.2, LED43.2, R219.2, R220.2, U$1119.P1, U$1119.P7, U$1119.P12
3.3V44: C133.1, C134.1, C135.1, I2C44.2, J221.2, J222.2, J223.2, LED44.2, R224.2, R225.2, U$1145.P1, U$1145.P7, U$1145.P12
3.3V45: C136.1, C137.1, C138.1, I2C45.2, J226.2, J227.2, J228.2, LED45.2, R229.2, R230.2, U$1171.P1, U$1171.P7, U$1171.P12
3.3V46: C139.1, C140.1, C141.1, I2C46.2, J231.2, J232.2, J233.2, LED46.2, R234.2, R235.2, U$1197.P1, U$1197.P7, U$1197.P12
3.3V47: C142.1, C143.1, C144.1, I2C47.2, J236.2, J237.2, J238.2, LED47.2, R239.2, R240.2, U$1223.P1, U$1223.P7, U$1223.P12
3.3V48: C145.1, C146.1, C147.1, I2C48.2, J241.2, J242.2, J243.2, LED48.2, R244.2, R245.2, U$1249.P1, U$1249.P7, U$1249.P12
3.3V49: C148.1, C149.1, C150.1, I2C49.2, J246.2, J247.2, J248.2, LED49.2, R249.2, R250.2, U$1275.P1, U$1275.P7, U$1275.P12
3.3V50: C151.1, C152.1, C153.1, I2C50.2, J251.2, J252.2, J253.2, LED50.2, R254.2, R255.2, U$1301.P1, U$1301.P7, U$1301.P12
3.3V51: C154.1, C155.1, C156.1, I2C51.2, J256.2, J257.2, J258.2, LED51.2, R259.2, R260.2, U$1327.P1, U$1327.P7, U$1327.P12
3.3V52: C157.1, C158.1, C159.1, I2C52.2, J261.2, J262.2, J263.2, LED52.2, R264.2, R265.2, U$1353.P1, U$1353.P7, U$1353.P12
3.3V53: C160.1, C161.1, C162.1, I2C53.2, J266.2, J267.2, J268.2, LED53.2, R269.2, R270.2, U$1379.P1, U$1379.P7, U$1379.P12
!INT!: J2.2, R1.1, U$1.P4
!INT!1: J9.2, R9.1, U$17.P4
!INT!2: J14.2, R14.1, U$53.P4
!INT!3: J19.2, R19.1, U$79.P4
!INT!4: J24.2, R24.1, U$105.P4
!INT!5: J29.2, R29.1, U$131.P4
!INT!6: J34.2, R34.1, U$157.P4
!INT!7: J39.2, R39.1, U$183.P4
!INT!8: J44.2, R44.1, U$209.P4
!INT!9: J49.2, R49.1, U$235.P4
!INT!10: J54.2, R54.1, U$261.P4
!INT!11: J59.2, R59.1, U$287.P4
!INT!12: J64.2, R64.1, U$313.P4
!INT!13: J69.2, R69.1, U$339.P4
!INT!14: J74.2, R74.1, U$365.P4
!INT!15: J79.2, R79.1, U$391.P4
!INT!16: J84.2, R84.1, U$417.P4
!INT!17: J89.2, R89.1, U$443.P4
!INT!18: J94.2, R94.1, U$469.P4
!INT!19: J99.2, R99.1, U$495.P4
!INT!20: J104.2, R104.1, U$521.P4
!INT!21: J109.2, R109.1, U$547.P4
!INT!22: J114.2, R114.1, U$573.P4
!INT!23: J119.2, R119.1, U$599.P4
!INT!24: J124.2, R124.1, U$625.P4
!INT!25: J129.2, R129.1, U$651.P4
!INT!26: J134.2, R134.1, U$677.P4
!INT!27: J139.2, R139.1, U$703.P4
!INT!28: J144.2, R144.1, U$729.P4
!INT!29: J149.2, R149.1, U$755.P4
!INT!30: J154.2, R154.1, U$781.P4
!INT!31: J159.2, R159.1, U$807.P4
!INT!32: J164.2, R164.1, U$833.P4
!INT!33: J169.2, R169.1, U$859.P4
!INT!34: J174.2, R174.1, U$885.P4
!INT!35: J179.2, R179.1, U$911.P4
!INT!36: J184.2, R184.1, U$937.P4
!INT!37: J189.2, R189.1, U$963.P4
!INT!38: J194.2, R194.1, U$989.P4
!INT!39: J199.2, R199.1, U$1015.P4
!INT!40: J204.2, R204.1, U$1041.P4
!INT!41: J209.2, R209.1, U$1067.P4
!INT!42: J214.2, R214.1, U$1093.P4
!INT!43: J219.2, R219.1, U$1119.P4
!INT!44: J224.2, R224.1, U$1145.P4
!INT!45: J229.2, R229.1, U$1171.P4
!INT!46: J234.2, R234.1, U$1197.P4
!INT!47: J239.2, R239.1, U$1223.P4
!INT!48: J244.2, R244.1, U$1249.P4
!INT!49: J249.2, R249.1, U$1275.P4
!INT!50: J254.2, R254.1, U$1301.P4
!INT!51: J259.2, R259.1, U$1327.P4
!INT!52: J264.2, R264.1, U$1353.P4
!INT!53: J269.2, R269.1, U$1379.P4
EN: J3.1, R2.1, U$1.P9
EN1: J10.1, R10.1, U$17.P9
EN2: J15.1, R15.1, U$53.P9
EN3: J20.1, R20.1, U$79.P9
EN4: J25.1, R25.1, U$105.P9
EN5: J30.1, R30.1, U$131.P9
EN6: J35.1, R35.1, U$157.P9
EN7: J40.1, R40.1, U$183.P9
EN8: J45.1, R45.1, U$209.P9
EN9: J50.1, R50.1, U$235.P9
EN10: J55.1, R55.1, U$261.P9
EN11: J60.1, R60.1, U$287.P9
EN12: J65.1, R65.1, U$313.P9
EN13: J70.1, R70.1, U$339.P9
EN14: J75.1, R75.1, U$365.P9
EN15: J80.1, R80.1, U$391.P9
EN16: J85.1, R85.1, U$417.P9
EN17: J90.1, R90.1, U$443.P9
EN18: J95.1, R95.1, U$469.P9
EN19: J100.1, R100.1, U$495.P9
EN20: J105.1, R105.1, U$521.P9
EN21: J110.1, R110.1, U$547.P9
EN22: J115.1, R115.1, U$573.P9
EN23: J120.1, R120.1, U$599.P9
EN24: J125.1, R125.1, U$625.P9
EN25: J130.1, R130.1, U$651.P9
EN26: J135.1, R135.1, U$677.P9
EN27: J140.1, R140.1, U$703.P9
EN28: J145.1, R145.1, U$729.P9
EN29: J150.1, R150.1, U$755.P9
EN30: J155.1, R155.1, U$781.P9
EN31: J160.1, R160.1, U$807.P9
EN32: J165.1, R165.1, U$833.P9
EN33: J170.1, R170.1, U$859.P9
EN34: J175.1, R175.1, U$885.P9
EN35: J180.1, R180.1, U$911.P9
EN36: J185.1, R185.1, U$937.P9
EN37: J190.1, R190.1, U$963.P9
EN38: J195.1, R195.1, U$989.P9
EN39: J200.1, R200.1, U$1015.P9
EN40: J205.1, R205.1, U$1041.P9
EN41: J210.1, R210.1, U$1067.P9
EN42: J215.1, R215.1, U$1093.P9
EN43: J220.1, R220.1, U$1119.P9
EN44: J225.1, R225.1, U$1145.P9
EN45: J230.1, R230.1, U$1171.P9
EN46: J235.1, R235.1, U$1197.P9
EN47: J240.1, R240.1, U$1223.P9
EN48: J245.1, R245.1, U$1249.P9
EN49: J250.1, R250.1, U$1275.P9
EN50: J255.1, R255.1, U$1301.P9
EN51: J260.1, R260.1, U$1327.P9
EN52: J265.1, R265.1, U$1353.P9
EN53: J270.1, R270.1, U$1379.P9
GND: C1.2, C2.2, C3.2, D2.C, J4.1, J5.1, J6.1, U$1.P2, U$1.P8, U$1.P11
GND1: C4.2, C5.2, C6.2, D1.C, J1.1, J7.1, J8.1, U$17.P2, U$17.P8, U$17.P11
GND2: C7.2, C8.2, C9.2, D3.C, J11.1, J12.1, J13.1, U$53.P2, U$53.P8, U$53.P11
GND3: C10.2, C11.2, C12.2, D4.C, J16.1, J17.1, J18.1, U$79.P2, U$79.P8, U$79.P11
GND4: C13.2, C14.2, C15.2, D5.C, J21.1, J22.1, J23.1, U$105.P2, U$105.P8, U$105.P11
GND5: C16.2, C17.2, C18.2, D6.C, J26.1, J27.1, J28.1, U$131.P2, U$131.P8, U$131.P11
GND6: C19.2, C20.2, C21.2, D7.C, J31.1, J32.1, J33.1, U$157.P2, U$157.P8, U$157.P11
GND7: C22.2, C23.2, C24.2, D8.C, J36.1, J37.1, J38.1, U$183.P2, U$183.P8, U$183.P11
GND8: C25.2, C26.2, C27.2, D9.C, J41.1, J42.1, J43.1, U$209.P2, U$209.P8, U$209.P11
GND9: C28.2, C29.2, C30.2, D10.C, J46.1, J47.1, J48.1, U$235.P2, U$235.P8, U$235.P11
GND10: C31.2, C32.2, C33.2, D11.C, J51.1, J52.1, J53.1, U$261.P2, U$261.P8, U$261.P11
GND11: C34.2, C35.2, C36.2, D12.C, J56.1, J57.1, J58.1, U$287.P2, U$287.P8, U$287.P11
GND12: C37.2, C38.2, C39.2, D13.C, J61.1, J62.1, J63.1, U$313.P2, U$313.P8, U$313.P11
GND13: C40.2, C41.2, C42.2, D14.C, J66.1, J67.1, J68.1, U$339.P2, U$339.P8, U$339.P11
GND14: C43.2, C44.2, C45.2, D15.C, J71.1, J72.1, J73.1, U$365.P2, U$365.P8, U$365.P11
GND15: C46.2, C47.2, C48.2, D16.C, J76.1, J77.1, J78.1, U$391.P2, U$391.P8, U$391.P11
GND16: C49.2, C50.2, C51.2, D17.C, J81.1, J82.1, J83.1, U$417.P2, U$417.P8, U$417.P11
GND17: C52.2, C53.2, C54.2, D18.C, J86.1, J87.1, J88.1, U$443.P2, U$443.P8, U$443.P11
GND18: C55.2, C56.2, C57.2, D19.C, J91.1, J92.1, J93.1, U$469.P2, U$469.P8, U$469.P11
GND19: C58.2, C59.2, C60.2, D20.C, J96.1, J97.1, J98.1, U$495.P2, U$495.P8, U$495.P11
GND20: C61.2, C62.2, C63.2, D21.C, J101.1, J102.1, J103.1, U$521.P2, U$521.P8, U$521.P11
GND21: C64.2, C65.2, C66.2, D22.C, J106.1, J107.1, J108.1, U$547.P2, U$547.P8, U$547.P11
GND22: C67.2, C68.2, C69.2, D23.C, J111.1, J112.1, J113.1, U$573.P2, U$573.P8, U$573.P11
GND23: C70.2, C71.2, C72.2, D24.C, J116.1, J117.1, J118.1, U$599.P2, U$599.P8, U$599.P11
GND24: C73.2, C74.2, C75.2, D25.C, J121.1, J122.1, J123.1, U$625.P2, U$625.P8, U$625.P11
GND25: C76.2, C77.2, C78.2, D26.C, J126.1, J127.1, J128.1, U$651.P2, U$651.P8, U$651.P11
GND26: C79.2, C80.2, C81.2, D27.C, J131.1, J132.1, J133.1, U$677.P2, U$677.P8, U$677.P11
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

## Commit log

2021-12-02 Adds an additional folder for second part
    [SparkFun_tDof-TMF8820.brd, SparkFun_tDof-TMF8820.sch, SparkFun_tDof-TMF8821.brd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]
2021-12-03 Routes entire board - rough draft
    [SparkFun_tDof-TMF8820.brd, SparkFun_tDof-TMF8820.sch]
2021-12-06 Adds silk to TMF8820, updates footprint with pin 1 indicator
    [SparkFun_tDof-TMF8820.brd, SparkFun_tDof-TMF8820.sch]
2021-12-06 Moves correct TMF8820 files into the correct folder
    [SparkFun_tDof-TMF8820.brd, SparkFun_tDof-TMF8820.sch]
2021-12-06 Copies 8820 and overwrites 8821 design files (no silk changes yet)
    [SparkFun_tDof-TMF8821.brd, SparkFun_tDof-TMF8821.sch]
2021-12-06 Adds "TMF8821" silk to the 8821 board design files
    * Replaces device with TMF8821 in schematic and updates text
    [SparkFun_tDof-TMF8821.brd, SparkFun_tDof-TMF8821.sch]
2021-12-06 Adds VCC Range to schematic in both designs
    [SparkFun_tDof-TMF8820.brd, SparkFun_tDof-TMF8820.sch, SparkFun_tDof-TMF8821.sch]
2021-12-06 Adds two more designs - the "half qwiic" size boards (it's what it sounds like)
    [SparkFun_tDof-TMF8820_HQ.brd, SparkFun_tDof-TMF8820_HQ.sch, SparkFun_tDof-TMF8821_HQ.brd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]
2021-12-06 Adds datasheets
    [RB_V2_06_02.STEP, RUBBERBOOT2.SLDDRW, RUBBERBOOT2.SLDPRT]
2021-12-07 Adds default address to HQ boards, fixes some clearance issues
    [SparkFun_tDof-TMF8820.brd, SparkFun_tDof-TMF8820_HQ.brd, SparkFun_tDof-TMF8820_HQ.sch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]
2021-12-08 Moves header to one side on the 1"x1" Qwiic Board
    [SparkFun_tDof-TMF8820.brd, SparkFun_tDof-TMF8820.sch]
2021-12-08 Updates the TMF882X device in the library to have two variants of the two ICs
    * Better silk labeling for the 8820 and 8820 HQ
    * Adds new IC variants to both designs
    * Adds default addresses to schematics
    * Moves some traces and vias for better ground pour in the 8820 design
    * Moves entire 8820 design to origin in board file
    * Adds measure from center of qwiic connector to edge in 8820 design
    [SparkFun_tDof-TMF8820.brd, SparkFun_tDof-TMF8820.sch, SparkFun_tDof-TMF8820_HQ.brd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]
2021-12-08 Copies 8820 designs to create 8821 designs - updates relevant references to 8820 to 8821
    [SparkFun_tDof-TMF8821.brd, SparkFun_tDof-TMF8821.sch, SparkFun_tDof-TMF8821_HQ.brd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]
2021-12-08 Approves some overlap errors on jumpers and ground wire "stub"
    [SparkFun_tDof-TMF8820.brd, SparkFun_tDof-TMF8820_HQ.brd, SparkFun_tDof-TMF8821.brd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]
2021-12-08 Adds logos to schematic
    * Moves measures to board (weren't moved when the design was put at the origin)
    * Replaces IO1 silk with IO0 on GPIO0 PTH header
    [SparkFun_tDof-TMF8820_HQ.brd, SparkFun_tDof-TMF8820_HQ.sch, SparkFun_tDof-TMF8821_HQ.brd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]
2021-12-09 Rotates "IO0" silk on bottom side of regular Qwiic versions of the product
    [SparkFun_tDof-TMF8820.brd, SparkFun_tDof-TMF8821.brd]
2021-12-09 Adds a two solder jumper for identifying whether the product has
    the 8820 or 8821 - to the 8820 Qwiic Board
    [SparkFun_tDof-TMF8820.brd, SparkFun_tDof-TMF8820.sch]
2021-12-09 Adds gerbers for prototypes
    [SparkFun_tDof-TMF8820.GBL, SparkFun_tDof-TMF8820.GBO, SparkFun_tDof-TMF8820.GBP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]
2022-02-21 Moves IC to one side and all parts to the other
    [SparkFun_tDof-TMF8820_HQ.brd]
2022-02-22 Moves the IC on the SparkFun "HQ" design to one side
    * All other parts are on the other side. This makes room for product selection boxes so that one PCB can be used for both.
    [SparkFun_tDof-TMF8820_HQ.brd, SparkFun_tDof-TMF8820_HQ.sch]
2022-02-22 Renames "HQ" files to "mini" to be consistent with new naming scheme
    [SparkFun_tDof-TMF8820_Mini.brd, SparkFun_tDof-TMF8820_Mini.sch]
2022-02-22 Removes old production files
    * Removes old 8821 "HQ" variants
    * Copies the 8820 and 8820 Mini variants
    * Adjusts new 8820 copies to reference 8821 and replaces 8820 with 8821
    * Updates Product Identifier jumpers to reflect changes
    [SparkFun_tDof-TMF8820.GBL, SparkFun_tDof-TMF8820.GBO, SparkFun_tDof-TMF8820.GBP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]
2022-02-23 Adds new product identifier pads to all designs, rolls 8820 version number to v10
    [SparkFun_tDof-TMF8820.brd, SparkFun_tDof-TMF8820.sch, SparkFun_tDof-TMF8820_Mini.brd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]
2022-02-23 Changes all "IO" silk to be "GP" instead, increases Qwiic pill size on mini's
    * Fixes orientation of I2C and LED silk on mini versions
    * Increases SparkFun flame size on mini versions
    [SparkFun_tDof-TMF8820.brd, SparkFun_tDof-TMF8820_Mini.brd, SparkFun_tDof-TMF8820_Mini.sch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]
2022-02-23 Adds OSHW logo to boards, fixes silk width of new product identifier pads
    [SparkFun_tDof-TMF8820_Mini.brd, SparkFun_tDof-TMF8820_Mini.sch, SparkFun_tDof-TMF8821_Mini.brd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]
2022-02-24 Adds production files for all products
    * The 8821 and 8821 Mini do not have their own PCBs
    * However they do have their own paste layers which I've included in the Production Files
    [SparkFun_tDof-TMF8820-Panel.GBL, SparkFun_tDof-TMF8820-Panel.GBO, SparkFun_tDof-TMF8820-Panel.GBP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]
2022-02-25 Fixes Sync silk on GP1 through hole on Qwiic sized designs
    [SparkFun_tDof-TMF8820.brd, SparkFun_tDof-TMF8821.brd]
2022-02-25 Adds new panel with corrected silk
    [SparkFun_tDof-TMF8820-Panel.brd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]
2022-04-07 Update File Names
    There was a minor typo in the file names. Changing all file names: tDoF => dToF
    [SparkFun_dToF-TMF8820-Panel.GBL, SparkFun_dToF-TMF8820-Panel.GBO, SparkFun_dToF-TMF8820-Panel.GBP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]
2022-04-07 Move to Hardware folder
    Move design files into Hardware folder
    [SparkFun_dToF-TMF8820.brd, SparkFun_dToF-TMF8820.sch, SparkFun_dToF-TMF8820_Mini.brd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]
2022-04-20 Removes library used for prototyping - sensor has been moved to main SparkFun Eagle Library

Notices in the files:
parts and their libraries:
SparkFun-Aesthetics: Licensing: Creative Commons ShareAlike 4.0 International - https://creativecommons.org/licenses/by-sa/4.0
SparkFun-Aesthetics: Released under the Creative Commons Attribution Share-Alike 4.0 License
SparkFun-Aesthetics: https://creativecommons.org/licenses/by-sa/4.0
